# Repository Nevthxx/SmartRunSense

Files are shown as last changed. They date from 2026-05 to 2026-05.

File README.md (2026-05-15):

🏃‍♂️ SmartRunSense

IoT-Based Environmental Monitoring and Prediction System

C++ · Python · scikit-learn · Google Cloud · Firebase · ESP32

📖 Overview
Outdoor running offers major physical and mental health benefits, but environmental conditions such as heat, humidity, particulate matter, and gas pollutants can introduce serious physiological stress.
SmartRunSense is an IoT-based environmental intelligence system designed to help runners make safer and more informed training decisions. It combines real-time sensor data, cloud infrastructure, and machine learning forecasting to provide both live and predictive environmental insights.
The system integrates wearable and stationary IoT nodes, cloud-based data storage, ML-driven forecasting, and a mobile application for visualization and decision support.

🗺️ System Architecture
SmartRunSense is built across four logical layers:
Edge Layer (IoT Devices):
Wearable devices and stationary Smart Poles equipped with environmental sensors.
Cloud Ingestion & Storage:
Google Firestore acts as the central real-time database.
Cloud Processing Layer:
Google Cloud Run microservice running a scikit-learn-based forecasting engine.
Application Layer:
Mobile app for live monitoring, historical analysis, and predictive insights.

✨ Key Features

📡 Real-Time Environmental Monitoring
Continuous data collection from wearable and Smart Pole IoT nodes.

🤖 Machine Learning Forecasting
Predicts environmental conditions up to 7 days ahead using a Random Forest Regressor.

📱 Mobile Application Dashboard
Provides live sensor data, analytics, and personalized run recommendations.

📅 Smart Scheduling System
Suggests optimal time slots for outdoor activity based on predicted environmental risk.

🛠️ Hardware Architecture
⌚ Wearable Device
Portable ESP32-based node (ESP32 DevKitC / ESP32-C3) designed for runners in motion.
🗼 Smart Pole (Stationary Node)
Fixed monitoring stations powered by ESP32-S3 for continuous environmental tracking in public areas.

🌡️ Sensor Suite
Both nodes integrate a shared set of sensors:
🌬️ ENS160 – Air quality (AQI, eCO₂, TVOC)
💧 AHT21 – Temperature & humidity
🏭 MQ135 – Gas pollution estimation (NOx, NH₃, smoke, benzene, etc.)
💨 SHARP GP2Y1010 – Dust/particulate matter detection
🧠 Machine Learning & Cloud Pipeline
⚙️ Execution: Cloud Run microservice triggered every 30 minutes via Cloud Scheduler
📊 Model: Random Forest Regressor (scikit-learn)
📈 Training Data: Last 14 days of sensor data (~20,000 records)
🔮 Forecast Horizon: 7 days ahead in 30-minute intervals (336 steps)
🎯 Outputs: Temperature, humidity, dust density, AQI, TVOC, CO₂, gas pollution %

🗄️ Database
🔥 Google Firestore
Stores real-time sensor readings and ML-generated forecasts with timestamped environmental metrics.

📱 Mobile Application
📊 Live Monitor: Real-time environmental conditions with a “Run Score” risk indicator
📅 Smart Schedule: Highlights safe vs risky time slots for outdoor running
📉 Analytics: Historical trends for air quality and pollutants
🌤️ Forecast: 7-day environmental predictions from the ML engine

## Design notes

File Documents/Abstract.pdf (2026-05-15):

## SmartRunSense: An IoT Based Environmental Monitoring and Prediction System for Safer Outdoor Running

## Abstract

Outdoor running is one of the most accessible and widely practiced forms of physical exercise, providing cardiovascular and mental health benefits. However, the thermodynamic and respiratory stresses experienced during outdoor training are strongly influenced by environmental conditions. Ambient temperature and humidity determine the rate of heat exchange between the body and the surroundings, while airborne particulate matter and gaseous pollutants alter respiratory efficiency and gas exchange (Brook et al., 2010; WHO, 2018). Understanding these interactions is critical for optimizing performance and reducing physiological risk during sustained exercise. Despite these risks, runners often rely on general weather forecasts that do not accurately represent localized environmental conditions at specific training tracks or open-air exercise spaces, which may expose them to heat stress, dehydration, or respiratory irritation without their knowledge (Li et al., 2019).

To address this challenge, SmartRunSense proposes an Internet of Things (IoT) based environmental monitoring and prediction system that enables runners to make informed decisions about when and where to train. The system combines real time environmental sensing, cloud based data storage, predictive analytics using machine learning, and a mobile application to provide both current and forecasted environmental conditions. By continuously monitoring atmospheric variables and analyzing their temporal patterns, the system identifies safer time periods for outdoor running and supports optimized training schedules.

The environmental monitoring component consists of stationary sensing units, referred to as Smart Poles, which collect high resolution data from multiple environmental sensors. Each Smart Pole is built around an ESP32 microcontroller, chosen for its Wi-Fi communication capabilities and low power consumption. Temperature and relative humidity are measured using an AHT21 digital sensor, enabling assessment of thermoregulatory stress via sweat evaporation efficiency. Air quality is evaluated using an ENS160 sensor, which provides measurements for Air Quality Index (AQI), equivalent carbon dioxide (eCO₂), and Total Volatile Organic Compounds (TVOC). Additional gas pollutants are estimated using a MQ135 sensor, while particulate concentration is measured using an optical dust sensor (GP2Y1010AU0F / DSM501A), which detects infrared light scattering caused by suspended particles. This multi-sensor setup captures a comprehensive environmental profile relevant to both thermodynamics and respiratory exposure (Kumar et al., 2015).

Data collected by the Smart Poles are transmitted via Wi-Fi to a cloud database (Google Firebase Firestore), where they are timestamped and stored. These continuous datasets enable the system to perform predictive analysis using a Random Forest regression model, trained on historical environmental data to forecast temperature, humidity, dust concentration, AQI, and pollutant levels at 30-minute intervals for up to seven days. By analyzing temporal features such as hour of the day and day of the week, the model identifies patterns and predicts periods when environmental conditions are safer for outdoor activity.

In parallel, SmartRunSense incorporates a wearable device that provides runners with real-time, localized environmental information in their breathing zone. The wearable is built on an ESP32-S3 microcontroller with integrated Wi-Fi and Bluetooth Low Energy (BLE), combined with an ENS160 air-quality sensor and AHT21 temperature and humidity sensor. The device measures eCO₂, TVOC, temperature, and humidity near the runner and displays these values on a compact OLED screen. A simple touch-based interface allows users to check current environmental conditions at a glance. Unlike the Smart Poles, the wearable does not transmit data to the cloud; it functions as an awareness tool, providing immediate feedback on the air the runner is breathing.

The SmartRunSense mobile application consolidates data from the Smart Poles and predictive model, allowing users to visualize both current environmental measurements and forecasted conditions. Parameters such as temperature, humidity, AQI, dust levels, and pollutant concentrations are presented in a user-friendly format. The app highlights recommended running periods based on predicted environmental safety, enabling runners to plan training sessions while minimizing exposure to heat stress or air pollutants.

By integrating environmental physics principles, IoT sensing, and predictive analytics, SmartRunSense offers a comprehensive system that supports safer outdoor exercise. It enables runners to make data driven decisions based on both the current conditions in their immediate environment and predictions of how these conditions may change over time. This combination of stationary monitoring, wearable awareness, machine learning based forecasting, and mobile visualization demonstrates the potential of technology driven environmental assessment to improve athletic safety and performance in outdoor activities.

## References

1. Brook, R. D., Rajagopalan, S., Pope III, C. A., Brook, J. R., Bhatnagar, A., Diez-Roux, A. V., ... & Kaufman, J. D. (2010). Particulate matter air pollution and cardiovascular disease: An update to the scientific statement from the American Heart
Association. Circulation, 121(21), 2331–2378.
2. World Health Organization (WHO). (2018). Air pollution and child health: Prescribing clean air. Geneva: WHO.
3. Li, X., et al. (2019). Wearable environmental sensing for personalized exposure assessment. Sensors, 19(11), 2573.
4. Kumar, P., et al. (2015). The rise of low-cost sensing for managing air pollution in cities. Environment International, 75, 199–205.

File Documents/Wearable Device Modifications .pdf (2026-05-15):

# SmartRunSense

## Wearable Device

ESP32 DevKitC vs ESP32-C3 Super Mini

## Shared Components: Sensors, Display & Battery

The following components are identical in both wearable builds. Specifications and usage are the same regardless of which microcontroller board is selected.

Component | Specification | DevKitC build | C3 Super Mini build

Sensors

ENS160 Air quality sensor | eCO₂: 400–65,000 ppm TVOC: 0–65,000 ppb AQI index · I²C · LGA-9 · 3×3×0.9 mm | ✓ Same | ✓ Same
AHT21 Temp + humidity | ±0.3°C, range −40 to +85°C ±2% RH · I²C · SMD · 3×3×0.8 mm | ✓ Same | ✓ Same
SSD1306 OLED 0.49" display | 64×32 px · I²C · ~14×11 mm glass Timeout off after 5 s, wake on touch | ✓ Same | ✓ Same

Power & Charging

LiPo battery 3.7 V rechargeable | 200 mAh · 3.7 V · JST SH 1.0 mm ~30×15×4 mm cell | 200 mAh | 200 mAh
MCP73831T LiPo charger IC | 100 mA single-cell · SOT-23-5 2.9×1.6 mm · USB-C input | ✓ Same | ✓ Same
USB-C connector Charge + flash | GCT USB4085 mid-mount 8.9×3.5 mm SMD | ✓ Same | ✓ Same

Touch Interface

Capacitive touch
User input button

Native ESP32 GPIO touch channel Exposed copper pad on PCB
surface

✓ Built-in GPIO ✓ Built-in GPIO

## Microcontroller Board Comparison

Direct comparison of the ESP32 DevKitC development board against the ESP32-C3 Super Mini for use in the SmartRunSense wearable. Green cells indicate the better choice for a wearable application; amber cells indicate where the DevKitC has an advantage.

Feature | ESP32 DevKitC | ESP32-C3 Super Mini

Hardware Specs

Board size | 55.3 × 28.0 mm | 22.5 × 18.0 mm
Board area | 1,548 mm² | 405 mm²
Processor | Xtensa LX6 dual-core | RISC-V single-core
Clock speed | 240 MHz | 160 MHz
Flash memory | 4 MB | 4 MB
SRAM | 520 KB | 400 KB
Usable GPIOs | 38 pins | 11 pins

Wireless

Wi-Fi | 802.11 b/g/n (Wi-Fi 4) | 802.11 b/g/n (Wi-Fi 4)
Bluetooth | BLE 4.2 | BLE 5.0
RF certification | FCC / CE (board) | FCC / CE (module)
Antenna | PCB trace on WROOM module | Built-in PCB trace

Power

Active current | ~80–120 mA | ~20–30 mA
Light sleep | ~10–15 mA | ~5 µA (deep sleep)
Est. battery life | ~3–5 h / 200 mAh | ~10–14 h / 200 mAh
Native USB OTG | No — needs CH340 bridge | Yes

Assembly & Soldering

Soldering method | Pin headers — plug in | SMD castellated pads
Support circuits needed | None — all on board | LDO + buttons + caps
Prototype difficulty | Very easy | Moderate
Production suitability | Poor — redundant parts | Good — compact custom PCB

GPIO Sufficiency for SmartRunSense

I²C (SDA + SCL) | ✓ 2 pins used | ✓ 2 pins used

Feature | ESP32 DevKitC | ESP32-C3 Super Mini
OLED RST + DC | ✓ 2 pins used | ✓ 2 pins used
Capacitive touch | ✓ 1 pin used | ✓ 1 pin used
Total GPIOs needed | 5 of 38 used | 5 of 11 used
Room for expansion | 33 GPIOs spare | 6 GPIOs spare

## Enclosure Box Size Comparison

Estimated enclosure dimensions for the assembled wearable device including board, sensors, OLED display, battery, and wiring clearance. Based on DevKitC box dimensions of 88 × 68 × 55 mm as the baseline.

Dimension | DevKitC wearable box | C3 Super Mini box | Saving

Enclosure Outer Dimensions

Length (longest side) | 88 mm | 55 mm | −33 mm (−37%)
Width | 68 mm | 58 mm | −10 mm (−15%)
Depth / height | 55 mm | 45 mm | −10 mm (−18%)

Volume & Area

Footprint area (L × W) | 5,984 mm² | 3,190 mm² | −2,794 mm² (−47%)
Total volume (L × W × D) | ~328,000 mm³ | ~143,550 mm³ | −184,450 mm³ (−56%)

What Drives the Size Reduction

Board length contribution | 55.3 mm board | 22.5 mm board | −32.8 mm saved
OLED glass (unchanged) | ~14 mm wide | ~14 mm wide | No change
Battery (unchanged) | ~30 × 15 mm | ~30 × 15 mm | No change
Wiring clearance | ~15 mm each side | ~10 mm each side | −5 mm / side
Depth (thinner layout) | 55 mm | ~45 mm | Flatter battery fit possible

Wrist Wearability

Fits standard watch case? | No — 88 mm too long | Marginal — 55 mm is borderline | Closer to wearable size
Recommended enclosure type | Belt clip / armband | Wrist band / armband | Better form factor

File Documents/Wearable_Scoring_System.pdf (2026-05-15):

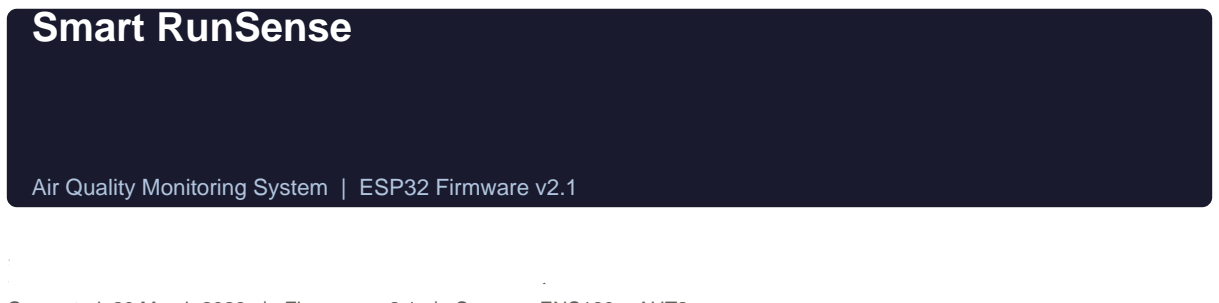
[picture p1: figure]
Smart RunSense

Air Quality Monitoring System | ESP32 Firmware v2.1
Scoring System Technical Report Mechanical Analysis of Air Quality Interpretation and Runner Score Computation
Generated: 20 March 2026 | Firmware: v2.1 | Sensors: ENS160 + AHT2x

### 1. System Overview

Smart RunSense is an embedded air quality monitoring system designed specifically for outdoor runners. Unlike standard Air Quality Index (AQI) systems that are calibrated for general population exposure over long periods, Smart RunSense computes a Runner Score — a real-time composite metric that accounts for both pollutant hazard and physical comfort conditions encountered during exercise. The score drives a five-band status classification displayed on the OLED screen and transmitted to Firebase Firestore.

Sensor | Parameter | Output Unit | Role in Score
ENS160 | eCO2 | ppm | Health AQI — primary
ENS160 | TVOC | ppb | Health AQI — primary
AHT2x | Temperature | °C | Comfort penalty
AHT2x | Humidity | % RH | Comfort penalty

Table 1 — Sensor inputs and their roles in the scoring pipeline.

### 2. Scoring Pipeline Architecture

The Runner Score is produced by a two-layer computation pipeline. Layer 1 evaluates atmospheric health through pollutant concentrations. Layer 2 applies a comfort-based scaling factor derived from temperature and humidity. The final score is bounded to [0, 100] and is intentionally asymmetric: poor air quality cannot be rescued by ideal comfort conditions, but extreme heat or humidity degrades performance even in chemically clean air.

Stage | Inputs | Output | Method
1a | eCO2 (ppm) | eCO2 Score | Piecewise linear
1b | TVOC (ppb) | TVOC Score | Piecewise linear
1c | Stage 1a + 1b | Health AQI | Dominant pollutant (min)
2a | Temperature (°C) | Temp Score | Piecewise linear
2b | Humidity (% RH) | Humidity Score | Piecewise linear
2c | Stage 2a + 2b | Comfort Score | Weighted blend 60/40
2d | Comfort Score | Comfort Multiplier | Linear scale [0.5 – 1.0]
3 | Health AQI x Multiplier | Runner Score | Multiplicative

Table 2 — Full computation pipeline with stage identifiers.

### 3. Individual Sensor Scoring Functions

### 3.1 eCO2 Score — getECO2Score(eco2)

Carbon dioxide equivalent (eCO2) is used as a proxy for overall indoor/outdoor air freshness and ventilation quality. The ENS160 derives eCO2 from metal oxide sensor readings, calibrated to the Adafruit AHT temperature and humidity sensor for temperature and RH compensation. Higher eCO2 concentrations indicate stale, poorly ventilated air which reduces oxygen availability for an exercising runner.

eCO2 Range (ppm) | Score | Condition
< 400 | 100.0 | Pristine — fresh outdoor air
400 – 5000 | Linear decrease from 100 to 0 | Moderate to severely polluted
> 5000 | 0.0 | Hazardous — do not run

Linear interpolation formula for 400 – 5000 ppm range:
eCO2 Score = max(0, 100 - ((eCO2 - 400) / 46.0))
Slope derivation: (100 - 0) / (5000 - 400) = 100 / 4600 = 0.02174 => 1/46.0 per ppm

### 3.2 TVOC Score — getTVOCScore(tvoc)

Total Volatile Organic Compounds (TVOC) represent a broad class of chemical pollutants including benzene, formaldehyde, and other volatile hydrocarbons. Elevated TVOC is associated with traffic emissions, industrial output, and off-gassing materials. During exercise, respiratory rate increases 10–20x, dramatically increasing pollutant intake, making TVOC a critical health factor for runners.

TVOC Range (ppb) | Score | WHO Classification
< 65 | 100.0 | Clean — no irritation
65 – 2200 | Linear decrease from 100 to 0 | Moderate to very high pollution
> 2200 | 0.0 | Extreme — hazardous exposure

Linear interpolation formula for 65 – 2200 ppb range:
TVOC Score = max(0, 100 - ((TVOC - 65) / 21.35))
Slope derivation: 100 / (2200 - 65) = 100 / 2135 = 0.04684 => 1/21.35 per ppb

### 4. Health AQI — Dominant Pollutant Model

The Health AQI does not average the two pollutant scores. Instead, it takes the strict minimum — the dominant pollutant model. This mirrors the methodology used by the US EPA's official AQI standard, where the overall air quality is determined by whichever single pollutant is worst.
Health AQI = min( eCO2 Score, TVOC Score )
Rationale: If eCO2 is excellent (Score = 95) but TVOC is dangerously high (Score = 12), averaging would produce a misleadingly acceptable result of 53.5. The dominant pollutant model correctly yields 12, accurately reflecting the hazardous chemical exposure the runner would experience.

### 5. Comfort Layer — Temperature and Humidity

### 5.1 Temperature Score — getTempScore(temp)

The optimal running temperature range is defined as 10 – 20°C based on exercise physiology research showing minimal cardiovascular strain and optimal thermoregulation in this window. Outside this range, the body expends additional energy on thermal regulation, reducing performance and increasing cardiac load.

Temperature Range | Score Formula | Physiological Rationale

10 – 20°C | 100.0 (flat) | Optimal running range
0 – 10°C | 50 + (T x 5.0) | Cold stress — muscle inefficiency
20 – 40°C | max(0, 100 - (T-20)x5) | Heat stress — hyperthermia risk
< 0°C or > 40°C | 0.0 | Extreme — dangerous to run

### 5.2 Humidity Score — getHumScore(hum)

Relative humidity directly affects the body's ability to cool itself through sweat evaporation. At humidity above 60%, sweat evaporation efficiency drops significantly, impairing thermoregulation. Below 40%, the air is too dry, increasing respiratory tract stress, dehydration risk, and airway irritation during heavy breathing.

Humidity Range | Score Formula | Effect
40 – 60% RH | 100.0 (flat) | Optimal evaporative cooling
10 – 40% RH | (H - 10) x 3.33 | Increasing dryness stress
60 – 90% RH | max(0, 100-(H-60)x3.33) | Decreasing sweat efficiency
< 10% or > 90% | 0.0 | Extreme — dangerous conditions

### 5.3 Comfort Score and Multiplier

Temperature and humidity scores are blended into a single Comfort Score using a weighted average that gives greater priority to temperature (60%) over humidity (40%), consistent with physiological evidence that ambient temperature is the stronger determinant of running performance degradation.
Comfort Score = (Temp Score x 0.6) + (Humidity Score x 0.4)
The Comfort Score is then converted to a multiplicative penalty factor — the Comfort Multiplier — which ranges from 0.5 (worst possible comfort) to 1.0 (perfect comfort). This multiplier is applied to the Health AQI.
Comfort Multiplier = 0.5 + (Comfort Score / 200.0)
At Comfort Score = 0: Multiplier = 0.5 (50% penalty — maximum degradation) At Comfort Score = 100: Multiplier = 1.0 (no penalty — perfect conditions)

### 6. Final Runner Score Computation

The Runner Score is the product of the Health AQI and the Comfort Multiplier:

### Runner Score = Health AQI x Comfort Multiplier

Expanding fully:
Runner Score = min(eCO2_Score, TVOC_Score) x [ 0.5 + (((Temp_Score x 0.6) + (Hum_Score x 0.4)) /
200) ]
Design Property | Behaviour | Why it Matters
Asymmetric penalty | Comfort cannot improve Health AQI above its raw value Prevents false reassurance in polluted environments
Dominant pollutant | Worst pollutant dictates Health AQI entirely | One toxic gas negates clean air elsewhere
Max comfort penalty | Even perfect air scores at most 50 in extreme heat/humidity Physiological limits respected regardless of air purity
Bounded output | Score always in [0, 100] | Consistent display and status classification

Table 3 — Key design properties of the Runner Score formula.

### 7. Status Classification Bands

The Runner Score is mapped to one of five status labels displayed on the OLED screen and stored in Firestore. The thresholds are calibrated to reflect real running safety guidelines rather than generic AQI categories:

DANGEROUS | UNSAFE | LIMIT | CAUTION | SAFE
0 | 30 | 50 | 70 | 85 | 100
Figure 1 — Runner Score status band distribution (0 – 100).
Score Range | Status | Recommended Action
85 – 100 | SAFE | Ideal conditions. Full training recommended.
70 – 84 | CAUTION | Acceptable. Monitor intensity, stay hydrated.
50 – 69 | LIMIT | Reduce intensity. Limit exposure time.
30 – 49 | UNSAFE | Avoid strenuous exercise. Short walks only.
0 – 29 | DANGEROUS | Do not run. Remain indoors if possible.

### 8. Worked Example — Typical Sri Lankan Afternoon Run

The following example demonstrates the full computation pipeline using realistic sensor values for a roadside urban run in Colombo at 3 PM:

Parameter | Sensor Reading | Sub-score
eCO2 | 780 ppm | Score = max(0, 100 - (780-400)/46.0) = 91.7
TVOC | 310 ppb | Score = max(0, 100 - (310-65)/21.35) = 88.5
Temperature | 32°C | Score = max(0, 100 - (32-20)x5) = 40.0
Humidity | 78% RH | Score = max(0, 100 - (78-60)x3.33) = 40.1

Step-by-step computation:
Health AQI = min(91.7, 88.5) = 88.5
Comfort Score = (40.0 x 0.6) + (40.1 x 0.4) = 24.0 + 16.04 = 40.04
Comfort Multiplier= 0.5 + (40.04 / 200.0) = 0.700
Runner Score = 88.5 x 0.700 = 61.95 → Status: LIMIT

Interpretation: Although the air pollutant levels are relatively acceptable (Health AQI = 88.5), the extreme heat and high humidity of a Colombo afternoon impose a 30% comfort penalty, pulling the final score into the LIMIT zone. The system correctly advises the runner to reduce intensity — a medically sound recommendation given the combined thermal and chemical stress.

### 9. Sensor Compensation

The ENS160 TVOC and eCO2 readings are temperature and humidity compensated in firmware before score calculation. The AHT2x readings are fed back into the ENS160 at each measurement cycle:

ens160.setTempCompensation(temp.temperature); ens160.setRHCompensation(hum.relative_humidity);
This ensures that elevated temperature does not artificially inflate eCO2 and TVOC readings, which is a common error in uncompensated metal oxide sensor deployments. All scores are therefore computed on environmentally corrected concentration values.

### 10. Data Output and Storage

Every 60 seconds, a complete measurement document is written to Google Firestore under the path sensor_data/esp32_0/readings/{YYYY-MM-DDTHH:MM}. The document includes all raw sensor values, all intermediate scores, the final Runner Score, and battery telemetry:

Firestore Field | Type | Description
temperature | double | AHT2x temperature (°C)
humidity | double | AHT2x relative humidity (%)
aqi | int | ENS160 native AQI index (1–5)
eco2 | int | Compensated eCO2 (ppm)
tvoc | int | Compensated TVOC (ppb)
runner_aqi | double | Computed Runner Score (0–100)
battery_voltage | double | Measured battery voltage (V)
battery_percent | int | Derived battery percentage (%)
timestamp | string | ISO 8601 timestamp (local time +05:30)
Smart RunSense | ESP32 Firmware v2.1 | Sensors: ENS160 + AHT2x | Scoring Engine: calculateRunnerAQI() | Report generated 20 March
2026

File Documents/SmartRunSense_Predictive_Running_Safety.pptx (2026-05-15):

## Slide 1

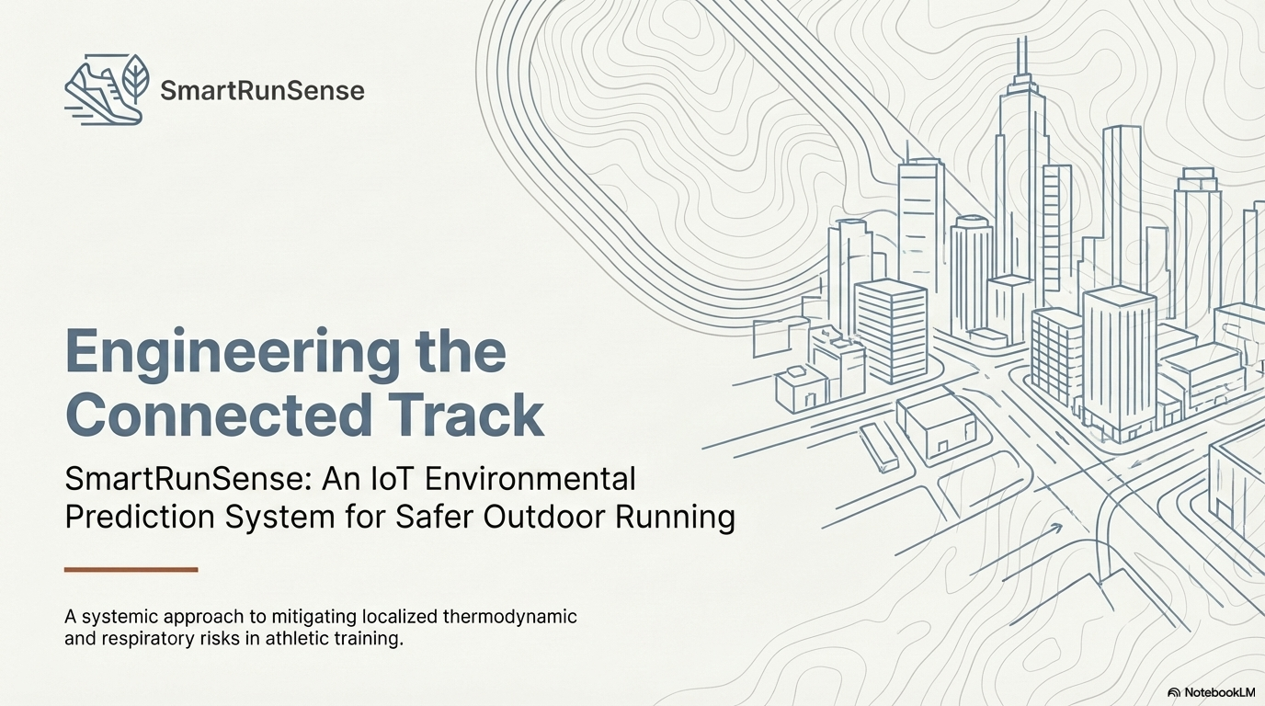
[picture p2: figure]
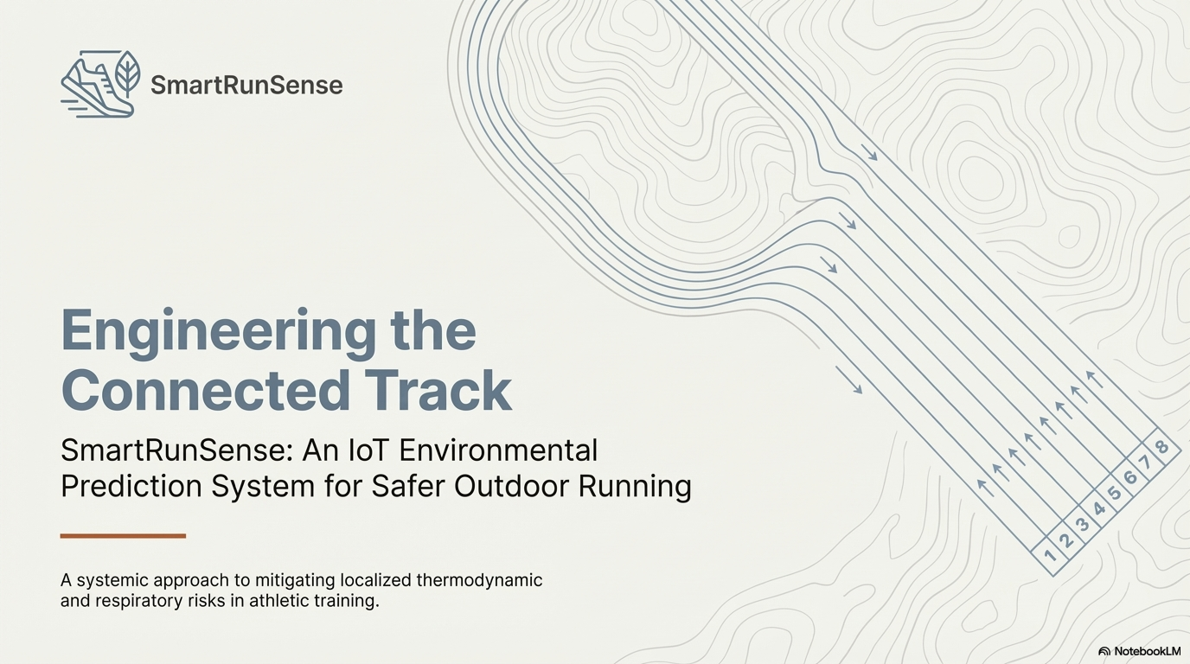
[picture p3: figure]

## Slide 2

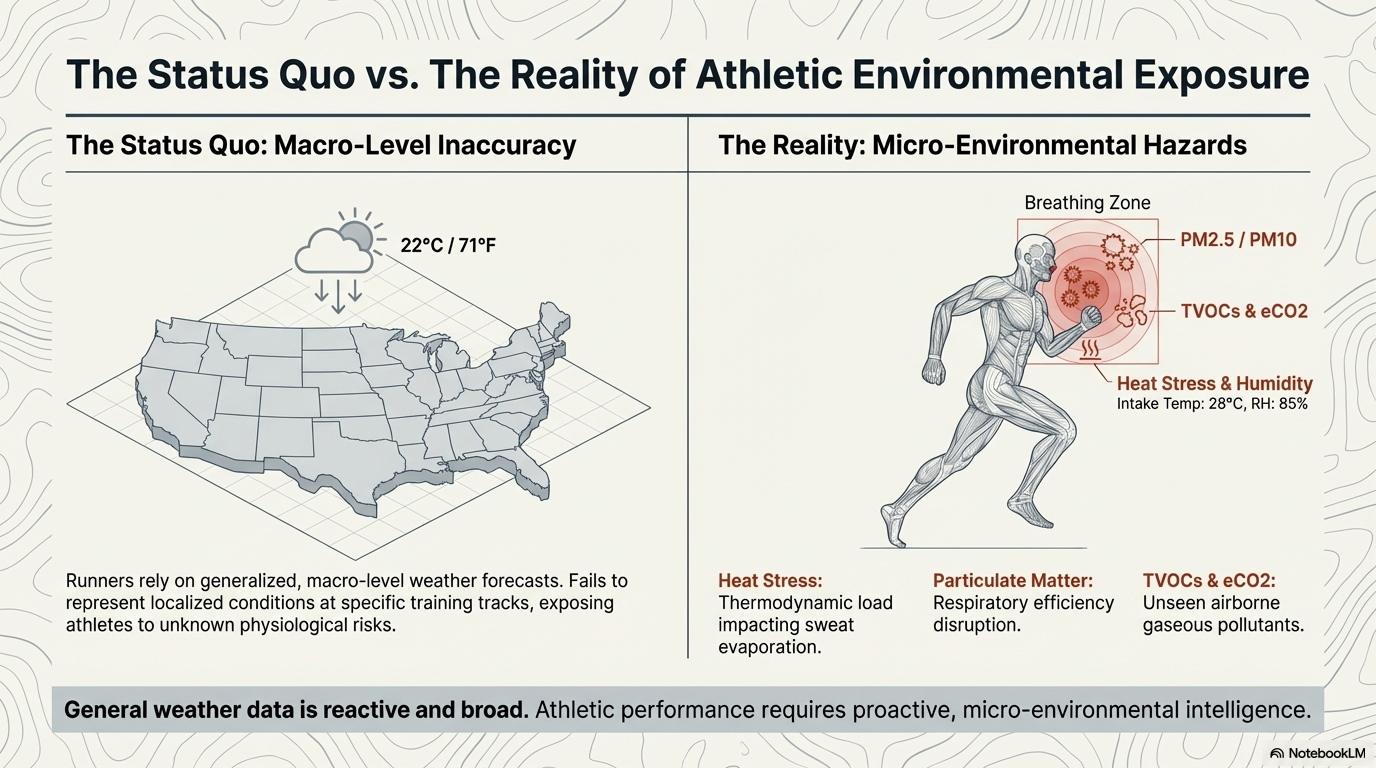
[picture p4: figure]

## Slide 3

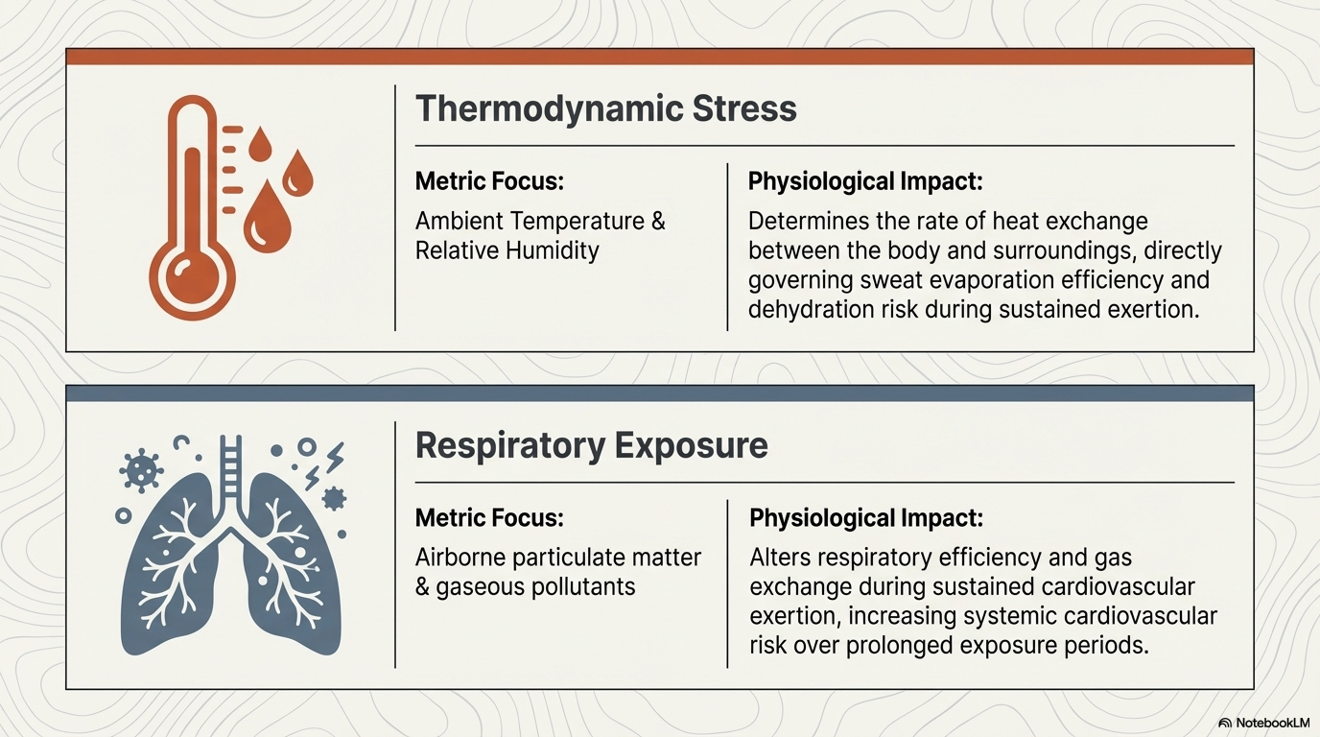
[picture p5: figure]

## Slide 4

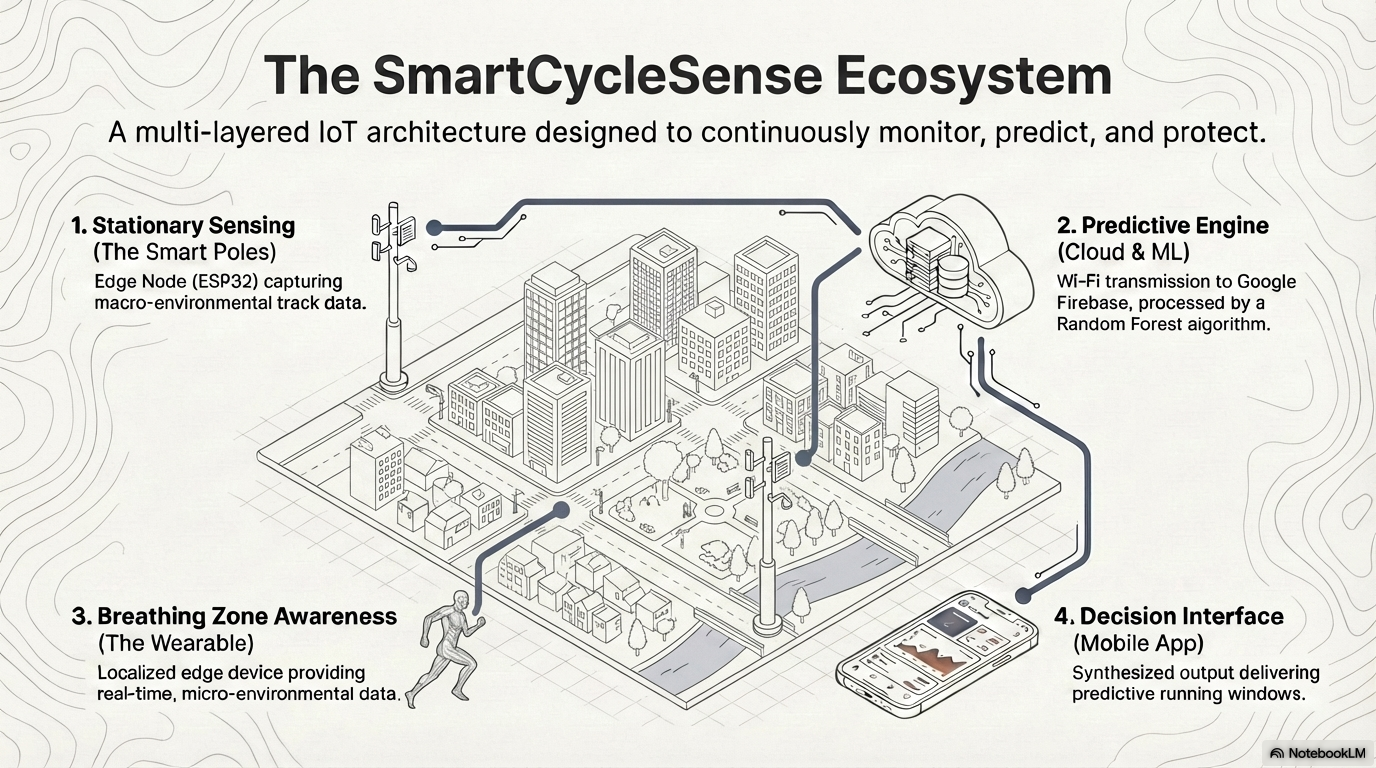
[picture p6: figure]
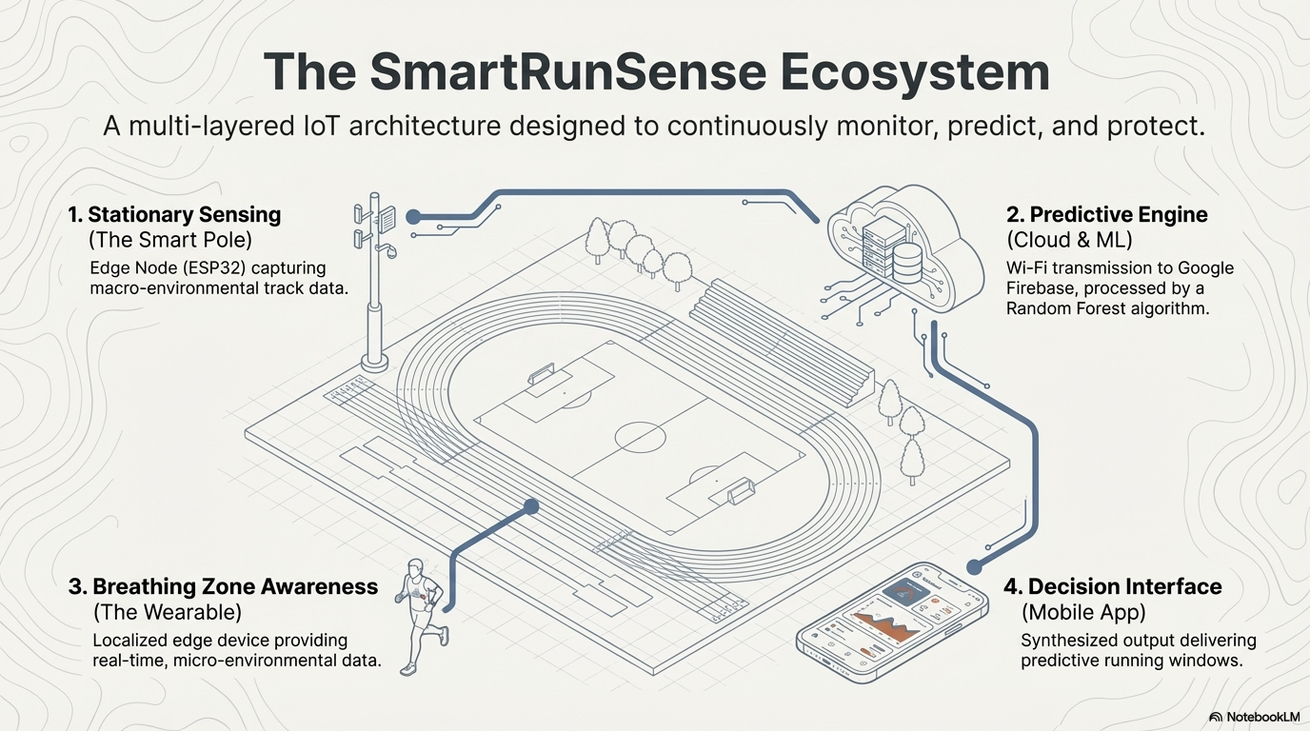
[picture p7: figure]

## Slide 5

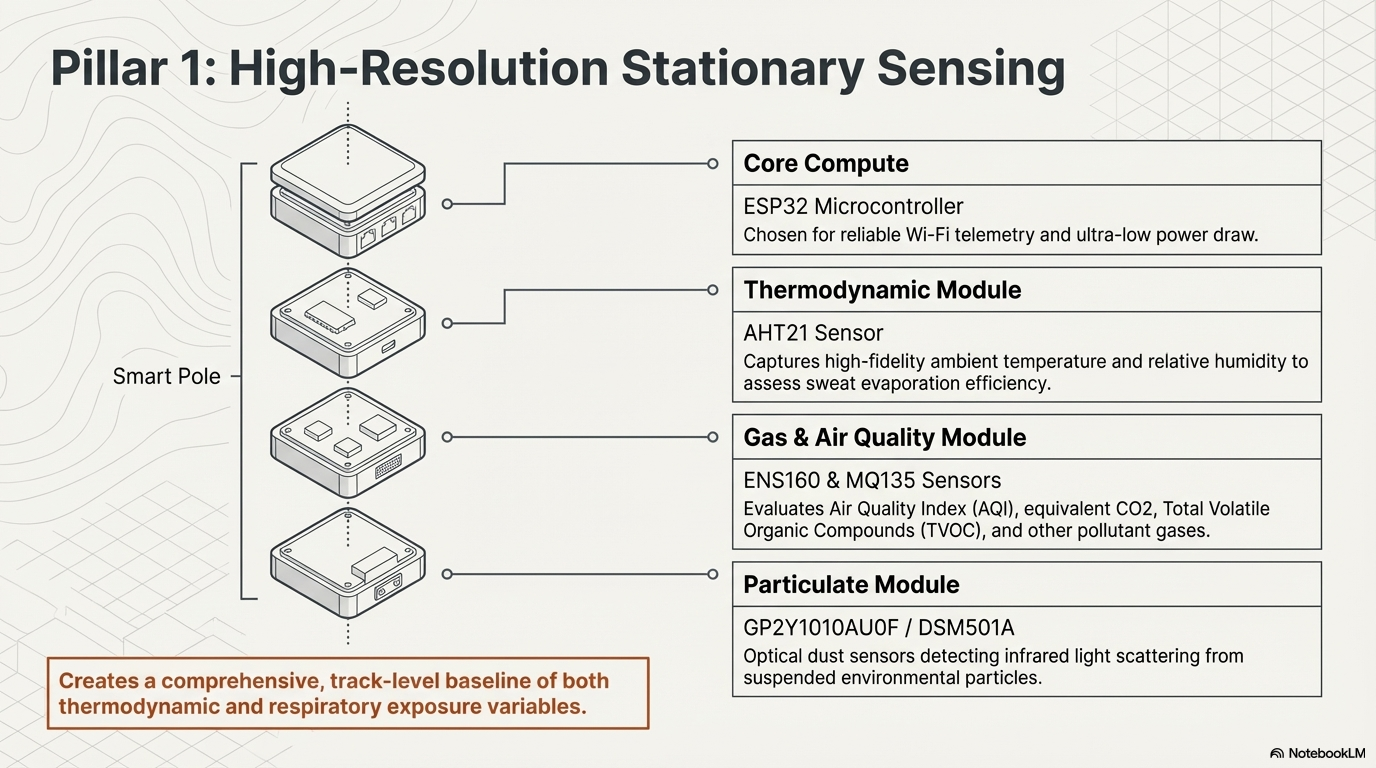
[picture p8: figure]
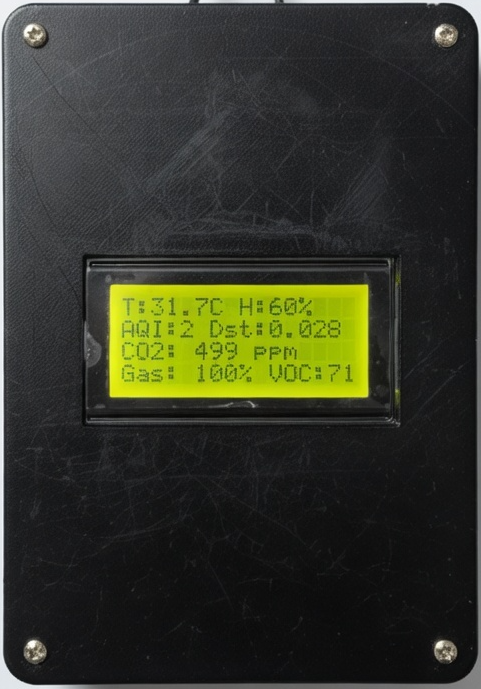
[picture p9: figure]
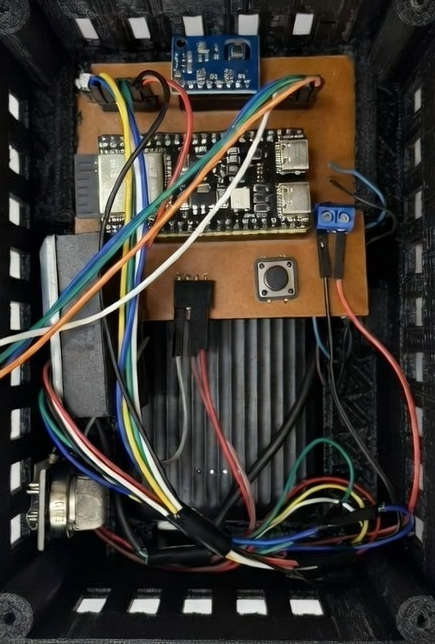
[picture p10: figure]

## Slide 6

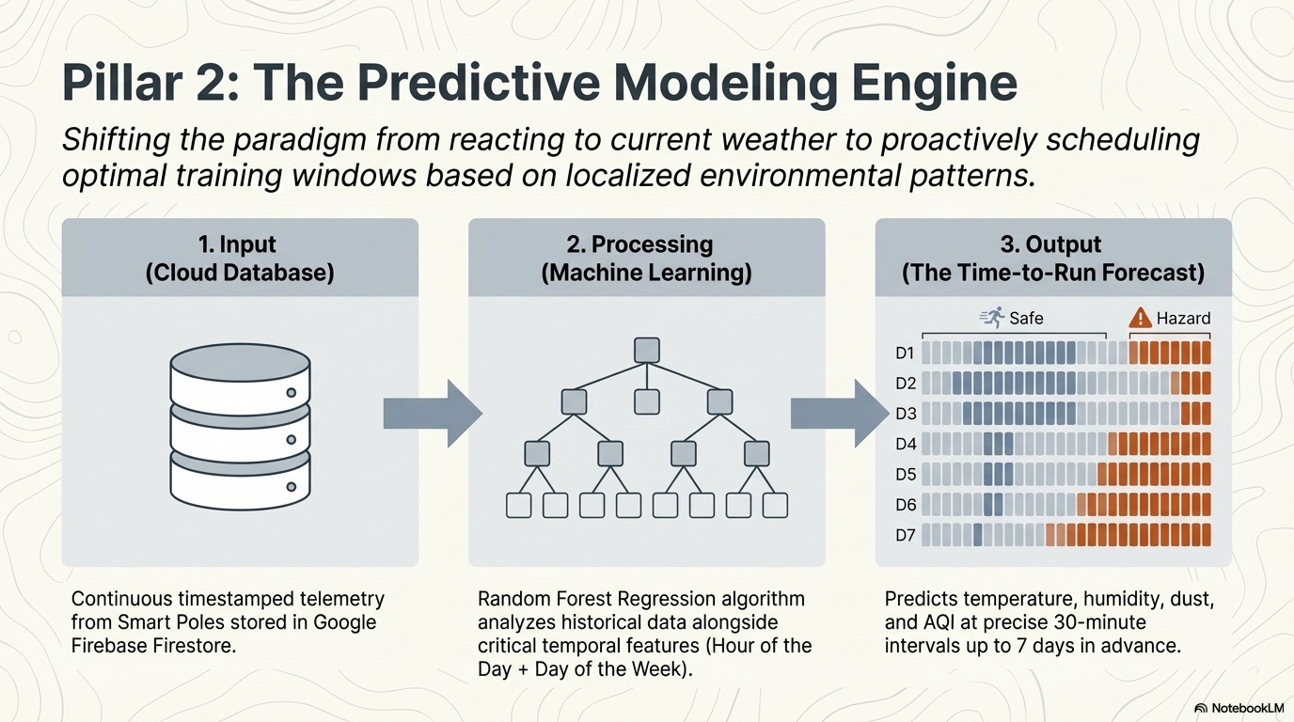
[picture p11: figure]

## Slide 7

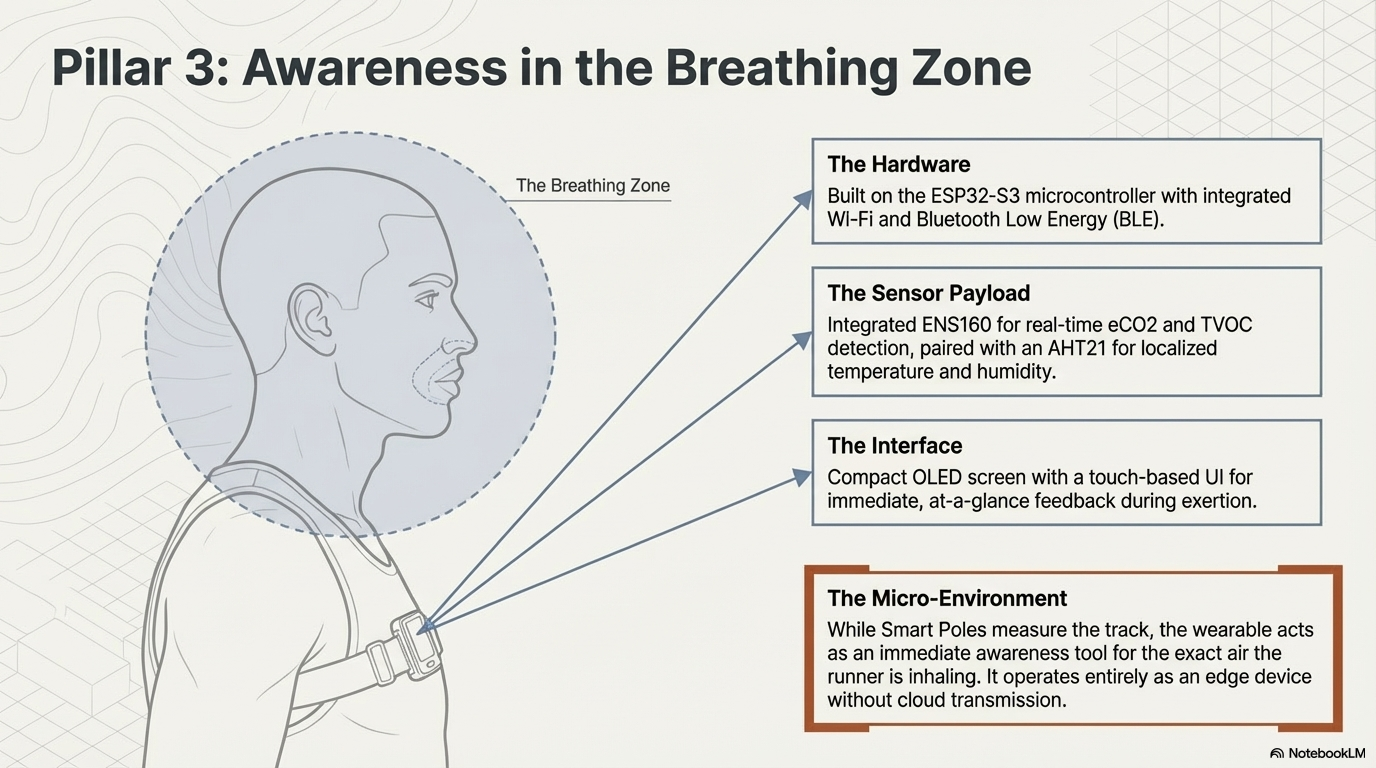
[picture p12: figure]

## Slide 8

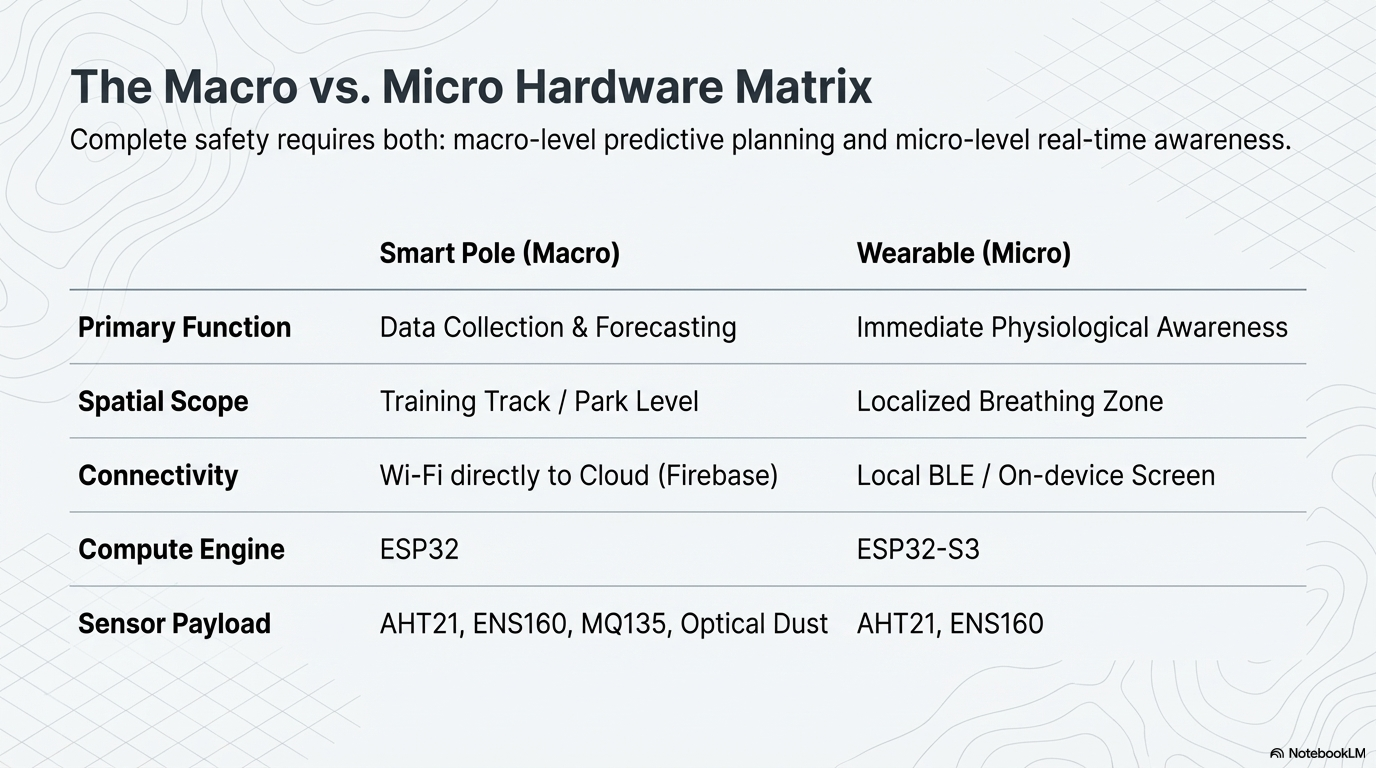
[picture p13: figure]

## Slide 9

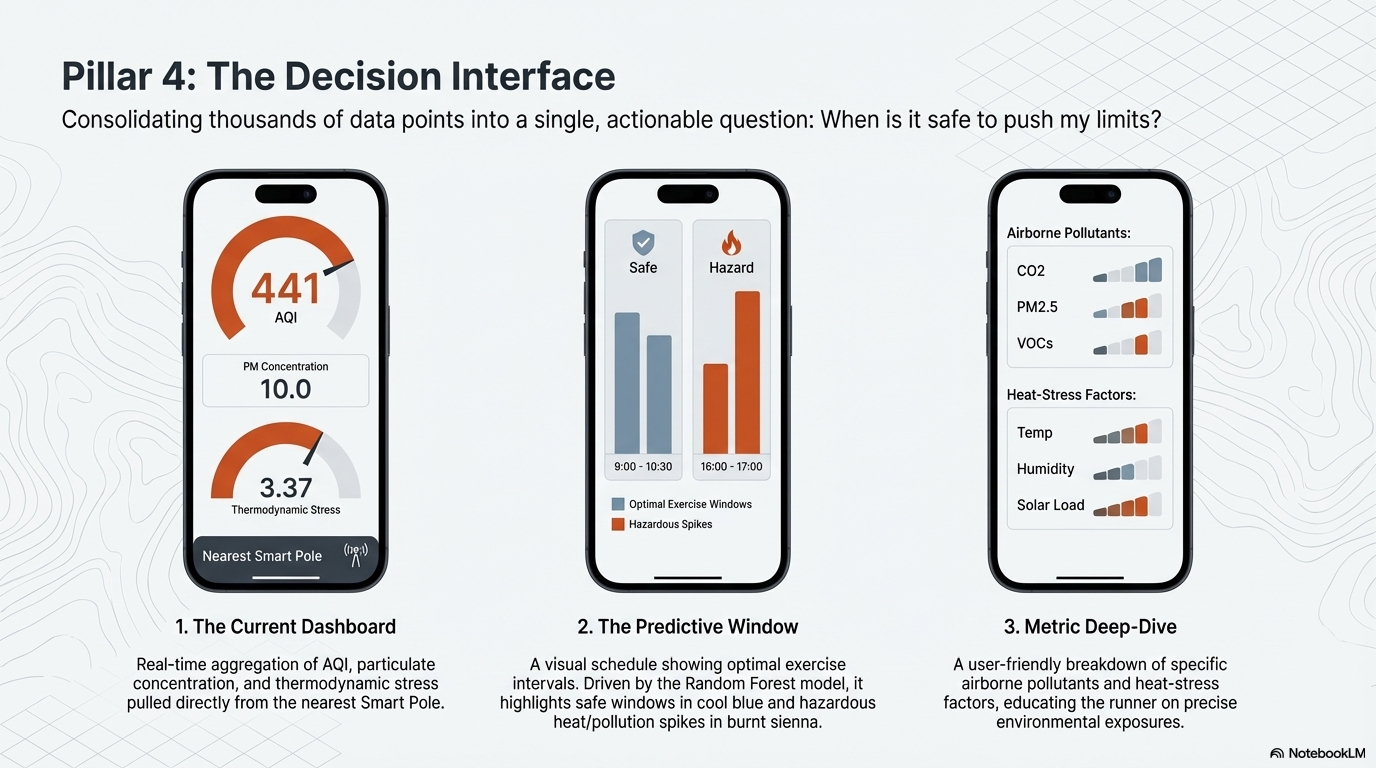
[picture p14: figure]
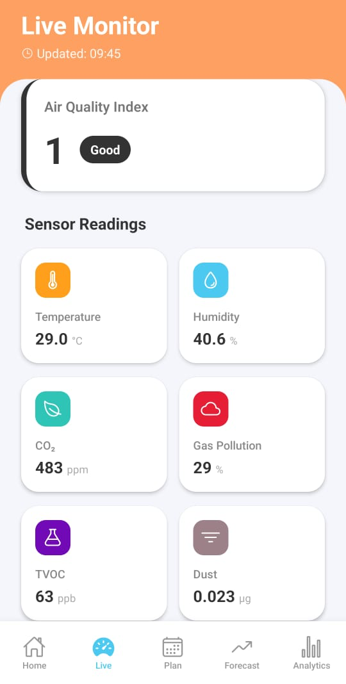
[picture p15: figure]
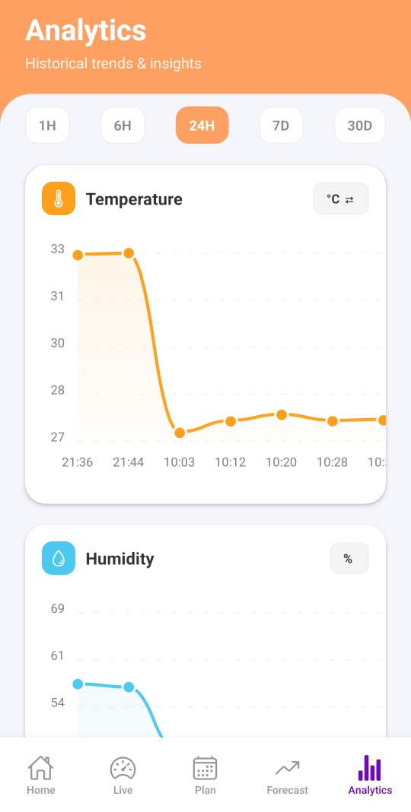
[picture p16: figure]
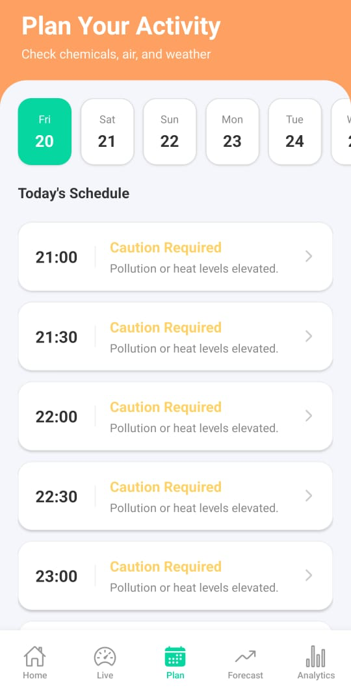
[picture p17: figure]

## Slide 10

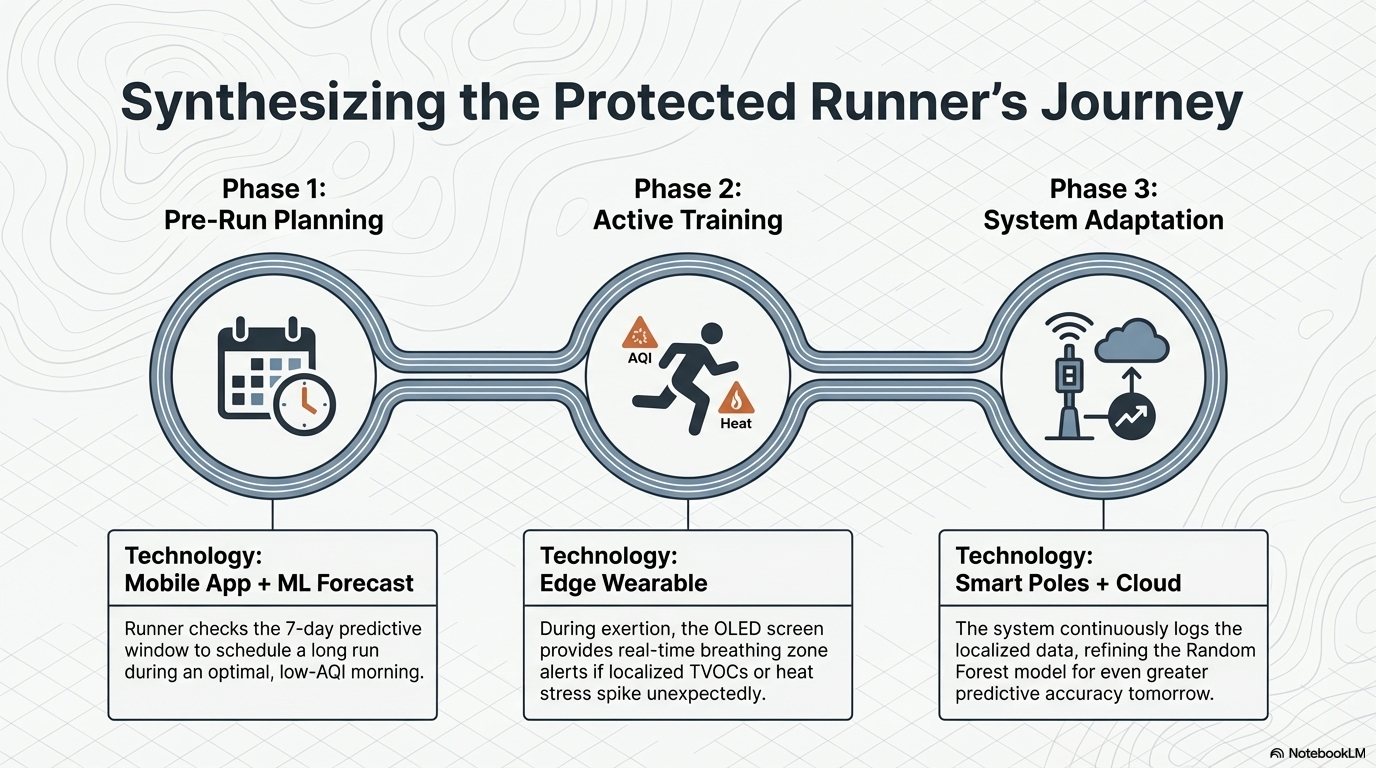
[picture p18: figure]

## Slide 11

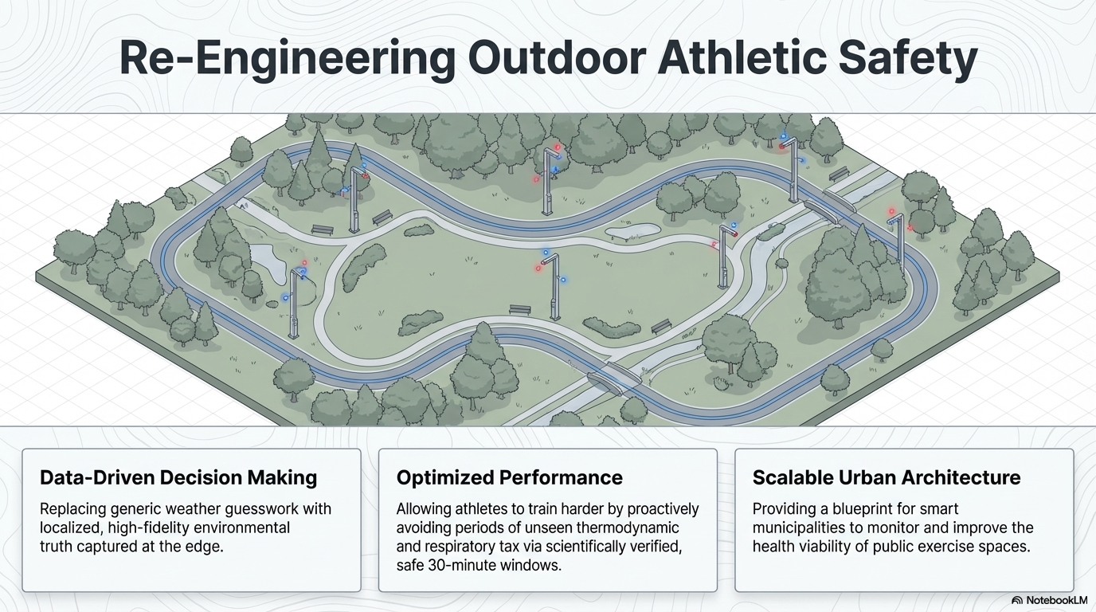
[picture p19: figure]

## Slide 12

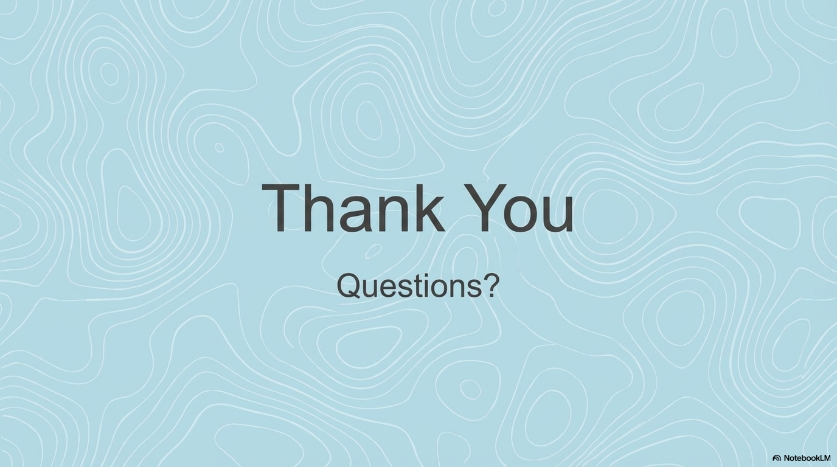
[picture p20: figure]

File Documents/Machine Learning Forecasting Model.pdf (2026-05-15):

## Machine Learning Forecasting Engine (Cloud Run Microservice)

### 1. System Overview

We built a Python program hosted on Google Cloud that automatically runs every 30 minutes. It reads the most recent environmental data, trains a new AI model on the spot, predicts future conditions, and uploads those results to our Firestore database.

### 2. Data Scope and Forecast Horizon

- Historical Data Used (The Input): The model queries the last 20,000 readings from Firestore, which roughly equates to the last 14 days of historical data. This 2-week window is specifically chosen to allow the model to learn daily patterns (e.g., temperatures rising at noon) as well as weekly cycles (e.g., weekends having different pollution levels than weekdays).
- Forecast Timeframe (The Output): The model predicts exactly 7 days into the future.
- Resolution: Predictions are generated in 30-minute intervals, resulting in 7 × 48 = 336 distinct prediction steps per execution.

### 3. The Variables (Features & Targets)

The model analyzes and predicts seven distinct environmental variables simultaneously:

1) Temperature
2) Humidity
3) Dust Density
4) AQI (Air Quality Index)
5) TVOC (Total Volatile Organic Compounds)
6) CO2 (eCO2-Equivalent Carbon Dioxide)
7) Gas Pollution Percentage (from the MQ135)

Each prediction is generated with the data and the time.

### 4. The Chosen Algorithm: Random Forest Regression

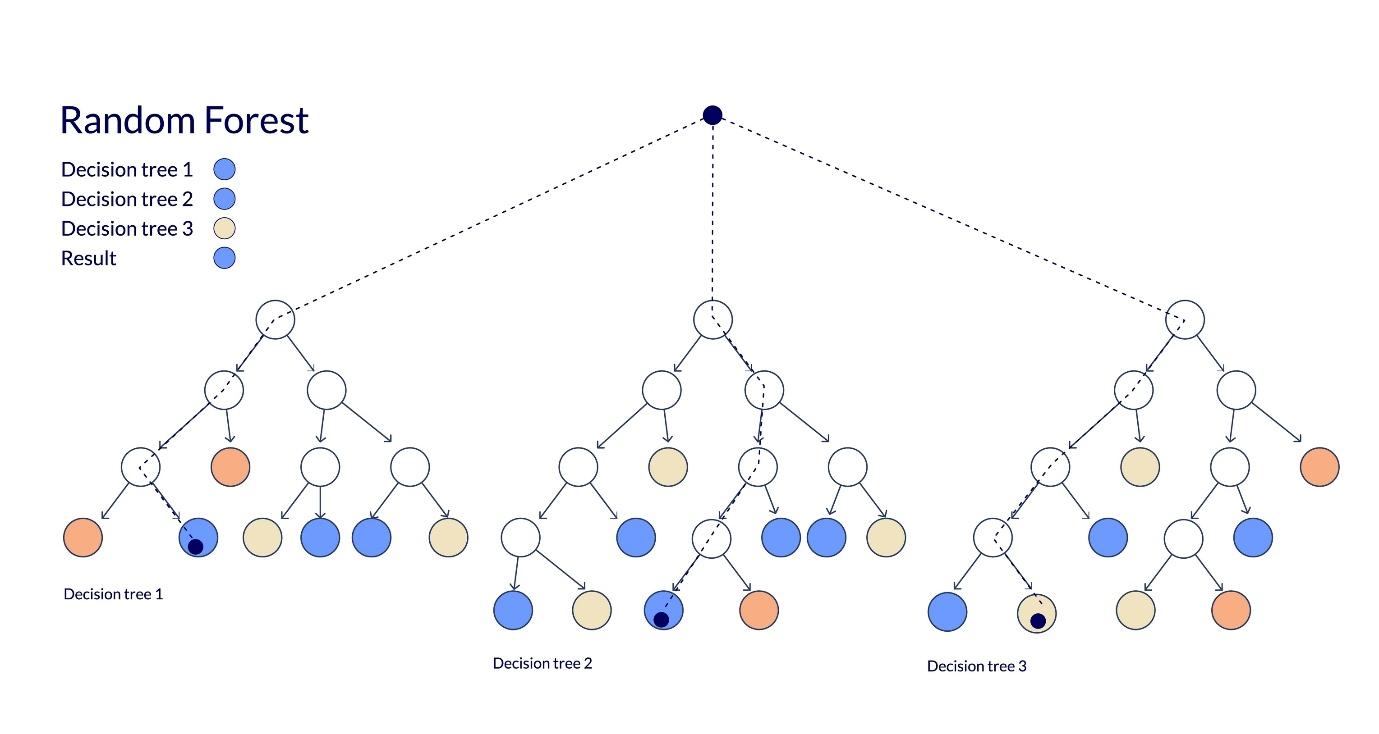
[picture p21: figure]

The code uses Random Forest Regressor from the scikit-learn library as the model. Random Forest is an ensemble learning method that builds dozens of "Decision Trees" during training and averages their predictions to output a highly accurate final result.

Why Random Forest was chosen over other algorithms:

- Handling Non-Linearity: Environmental data is highly non-linear. Linear Regression fails here, but Random Forest handles non-linear spikes exceptionally well.
- Compute Efficiency for Cloud Run: While Deep Learning models like LSTMs (Long Short-Term Memory networks) are great for time-series, they require heavy computing power, GPUs, and long training times. Random Forest trains in a matter of seconds using standard CPUs, making it perfect for a lightweight, cost-effective Cloud Run environment that triggers every 30 minutes.
- No Data Scaling Required: Neural networks require all data to be strictly normalized (scaled between 0 and 1). Random Forests do not care about the scale of the data, meaning we can feed raw Temperature (e.g., 30°C) and raw eCO2 (e.g., 400ppm) into the exact same model without complex pre-processing.

### 5. The Crucial Mechanism: How the Model Predicts the Future

The most critical part of this architecture is how it handles the time-series forecasting. It uses a technique called Autoregressive Recursive Forecasting.

Here is the exact step-by-step mechanism the code follows to predict the future:

Step 1: Resampling the Data;

- Sensor data can be messy and irregular. To fix this, our system automatically put the raw data into neat 30-minute intervals for the 14 days, giving the AI a clean and consistent timeline to learn from.
Step 2: Training 7 Parallel Models;

The code does not train just one model. It initializes a loop and trains seven separate Random Forest models. One dedicated entirely to Temperature, one to AQI, one to Dust, etc. Each model learns how its specific variable behaves based on the previous 30-minute window of all combined variables.

The Training Phase (Using all 14 Days): The model uses the full 14 days of data, but only to study and learn the rules.

- When the time is 12:00 PM, the temperature usually goes up.
- When AQI is high at 2:00 PM, it usually stays high at 2:30 PM.
- Weekends have less CO2 than weekdays.

Once the AI finishes reading those 14 days, it builds its Random Forest "brain" and completely throws the historical data away.

Step 3: The Recursive Prediction Loop (The "Sliding Window")

To predict 7 days into the future, the code relies on a feedback loop:

1) The Starting Point: It takes the very last known real sensor reading (e.g., today at 12:00 PM).
2) Step 1 Prediction: It feeds that real data into the ML models to predict what the air will look like at 12:30 PM.
3) The Feedback Loop: To predict 1:00 PM, the model no longer has real data. Therefore, it takes its own 12:30 PM prediction and feeds it back into itself as the new input to generate the 1:00 PM prediction.
4) Iteration: This cycle repeats 336 times. The outputs of step N become the inputs for step N+1, chaining together to generate a full 7-day forecast.

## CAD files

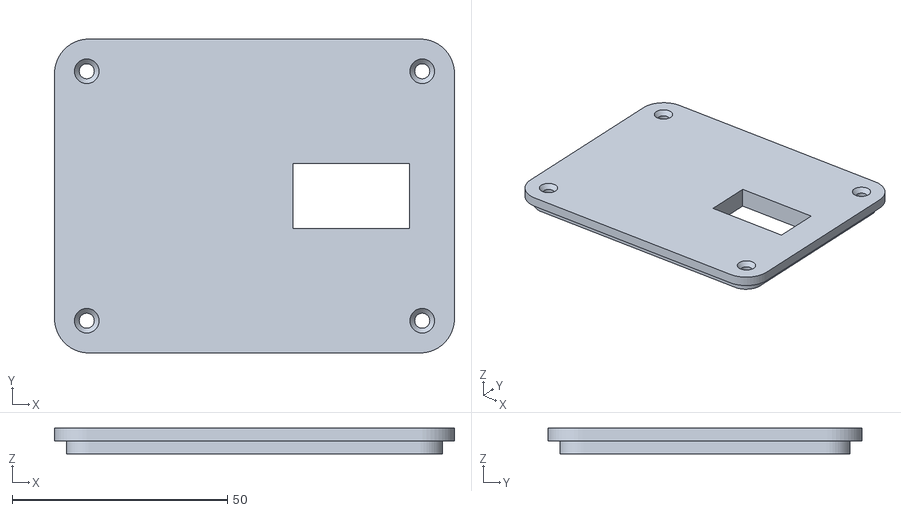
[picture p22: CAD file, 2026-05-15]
3D Design/Wearable_Lid.stl
93.0 x 73.0 x 6.00

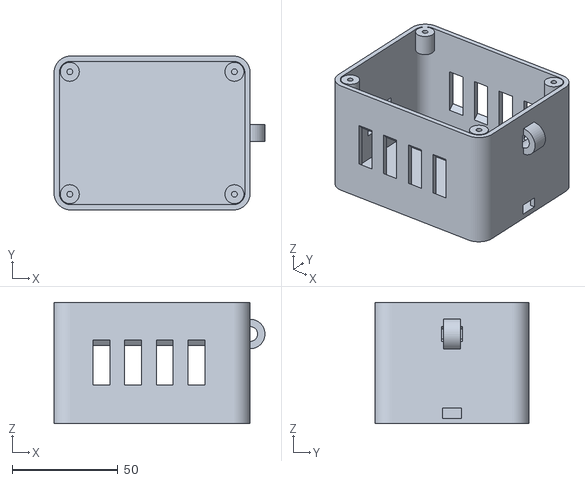
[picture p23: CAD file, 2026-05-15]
3D Design/Wearable_Box.stl
100.0 x 73.0 x 57.5

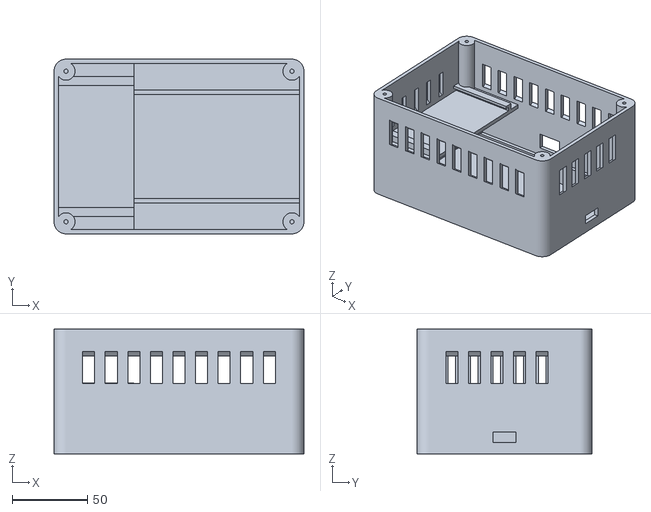
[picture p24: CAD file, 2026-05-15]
3D Design/Pole_Box.stl
166.0 x 116.0 x 83.0

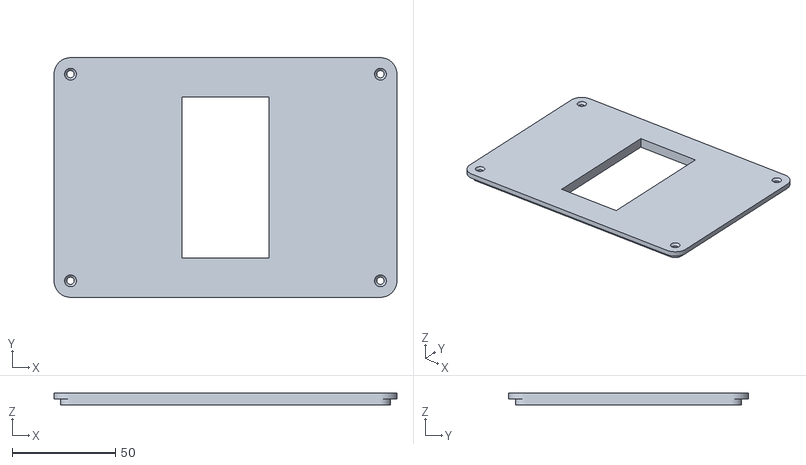
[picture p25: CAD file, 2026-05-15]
3D Design/Pole_Lid.stl
166.0 x 116.0 x 6.00

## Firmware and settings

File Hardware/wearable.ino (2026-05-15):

#include <WiFi.h>
#include <HTTPClient.h>
#include <ArduinoJson.h>
#include <WiFiClientSecure.h>
#include <time.h>
#include <Wire.h>
#include <SparkFun_ENS160.h>
#include <Adafruit_AHTX0.h>
#include <Adafruit_GFX.h>
#include <Adafruit_SSD1306.h>

/* ---------- OLED Display ---------- */
#define SCREEN_WIDTH 128
#define SCREEN_HEIGHT 64
#define OLED_RESET    -1 
#define SCREEN_ADDRESS 0x3C 

Adafruit_SSD1306 display(SCREEN_WIDTH, SCREEN_HEIGHT, &Wire, OLED_RESET);

/* ---------- WiFi ---------- */
#define WIFI_SSID "YOUR_WIFI_NAME"
#define WIFI_PASS "YOUR_WIFI_PASSWORD"

/* ---------- Firebase ---------- */
#define API_KEY    "YOUR_API_KEY"
#define PROJECT_ID "YOUR_PROJECT_ID"

/* ---------- Battery Monitoring ---------- */
#define BATTERY_PIN 6  // GPIO6 (ADC1_CH7) for battery voltage divider
#define ADC_RESOLUTION 4095.0  // 12-bit ADC
#define ADC_REF_VOLTAGE 3.3    // Reference voltage in volts
#define VOLTAGE_DIVIDER_RATIO 6.639  // Two equal resistors = ratio of 2

// Battery voltage thresholds (adjust based on your battery type)
// For LiPo: 4.2V = 100%, 3.7V = ~50%, 3.0V = 0%
#define BATTERY_MAX_VOLTAGE 4.2
#define BATTERY_MIN_VOLTAGE 3.2

/* ---------- Touch Sensor for Deep Sleep ---------- */
#define TOUCH_PIN 13  // GPIO 13 for TTP223 touch sensor

/* ---------- Sensors ---------- */
SparkFun_ENS160 ens160;
Adafruit_AHTX0 aht;

/* ---------- Timing ---------- */
unsigned long lastRead = 0;
const unsigned long READ_INTERVAL = 60000;

/* ---------- Touch Control ---------- */
unsigned long lastTouchTime = 0;
const unsigned long TOUCH_DEBOUNCE = 500;  // 500ms debounce
int lastTouchState = LOW;

/* ---------- RTC Memory (survives deep sleep) ---------- */
RTC_DATA_ATTR int bootCount = 0;  // Counts how many times we've woken up

String idToken = "";

/* ---------- Battery Functions ---------- */

// Read battery voltage from ADC
float readBatteryVoltage() {
  // Take multiple readings for accuracy
  int adcSum = 0;
  const int numReadings = 10;
  
  for (int i = 0; i < numReadings; i++) {
    adcSum += analogRead(BATTERY_PIN);
    delay(10);
  }
  
  int adcValue = adcSum / numReadings;
  
  // Convert ADC value to voltage at the divider (half of battery voltage)
  float dividerVoltage = (adcValue / ADC_RESOLUTION) * ADC_REF_VOLTAGE;
  
  // Calculate actual battery voltage (multiply by divider ratio)
  float batteryVoltage = dividerVoltage * VOLTAGE_DIVIDER_RATIO;
  
  return batteryVoltage;
}

// Calculate battery percentage
int getBatteryPercentage(float voltage) {
  if (voltage >= BATTERY_MAX_VOLTAGE) return 100;
  if (voltage <= BATTERY_MIN_VOLTAGE) return 0;
  
  // Linear interpolation between min and max
  float percentage = ((voltage - BATTERY_MIN_VOLTAGE) / 
                     (BATTERY_MAX_VOLTAGE - BATTERY_MIN_VOLTAGE)) * 100.0;
  
  return constrain((int)percentage, 0, 100);
}

// Get battery icon character based on percentage
String getBatteryIcon(int percentage) {
  if (percentage >= 80) return "====";
  else if (percentage >= 60) return "=== ";
  else if (percentage >= 40) return "==  ";
  else if (percentage >= 20) return "=   ";
  else return "!   "; // Low battery warning
}

/* ---------- Time ---------- */
String isoTimestampUTC() {
  time_t now;
  time(&now);
  struct tm utc;
  gmtime_r(&now, &utc);
  char buf[30];
  strftime(buf, sizeof(buf), "%Y-%m-%dT%H:%M:%SZ", &utc);
  return String(buf);
}

String localTimestamp() {
  struct tm t;
  getLocalTime(&t);
  char buf[30];
  strftime(buf, sizeof(buf), "%Y-%m-%d %H:%M:%S", &t);
  return String(buf);
}

String minuteDocId() {
  struct tm t;
  getLocalTime(&t);
  char buf[20];
  strftime(buf, sizeof(buf), "%Y%m%d_%H%M", &t);
  return String(buf);
}

/* ---------- Run Score Calculation ---------- */

// Convert eCO2 to score (0-100)
float getECO2Score(int eco2) {
  // Lower CO2 is better
  // < 400 ppm = 100, 400-1000 = linear decrease, > 5000 = 0
  if (eco2 < 400) return 100.0;
  if (eco2 > 5000) return 0.0;
  return max(0.0, 100.0 - ((eco2 - 400) / 46.0));
}

// Convert TVOC to score (0-100)
float getTVOCScore(int tvoc) {
  // Lower TVOC is better
  // < 65 ppb = 100, 65-220 = good, 220-660 = moderate, > 2200 = 0
  if (tvoc < 65) return 100.0;
  if (tvoc > 2200) return 0.0;
  return max(0.0, 100.0 - ((tvoc - 65) / 21.35));
}

// Convert Temperature to score (0-100)
float getTempScore(float temp) {
  // Optimal running temp: 10-20°C
  // 10-20°C = 100, decrease outside this range
  if (temp >= 10 && temp <= 20) return 100.0;
  if (temp < 0 || temp > 40) return 0.0;
  
  if (temp < 10) {
    // 0°C = 50, 10°C = 100
    return 50.0 + (temp * 5.0);
  } else {
    // 20°C = 100, 40°C = 0
    return max(0.0, 100.0 - ((temp - 20) * 5.0));
  }
}

// Convert Humidity to score (0-100)
float getHumScore(float hum) {
  // Optimal humidity: 40-60%
  // 40-60% = 100, decrease outside this range
  if (hum >= 40 && hum <= 60) return 100.0;
  if (hum < 10 || hum > 90) return 0.0;
  
  if (hum < 40) {
    // 10% = 0, 40% = 100
    return (hum - 10) * 3.33;
  } else {
    // 60% = 100, 90% = 0
    return max(0.0, 100.0 - ((hum - 60) * 3.33));
  }
}

// Calculate Runner AQI (0-100)
float calculateRunnerAQI(int eco2, int tvoc, float temp, float hum) {
  float eco2_score = getECO2Score(eco2);
  float tvoc_score = getTVOCScore(tvoc);

  // 2. DOMINANT POLLUTANT: Health is dictated strictly by the WORST metric
  float health_aqi = min(eco2_score, tvoc_score);

  float temp_score = getTempScore(temp);
  float hum_score = getHumScore(hum);

  // Comfort is a blend of heat and humidity
  float comfort_score = (temp_score * 0.6) + (hum_score * 0.4); 
  
  // 4. Apply Comfort as a Scaling Penalty
  // Poor comfort degrades a runner's performance even in perfect air,
  // but perfect comfort cannot magically fix toxic air.
  // This multiplier ranges from 0.5 (terrible comfort) to 1.0 (perfect comfort).
  float comfort_multiplier = 0.5 + (comfort_score / 200.0);
  
  float runner_aqi = health_aqi * comfort_multiplier;

  return runner_aqi;
}

// Get status based on Runner AQI
String getStatus(float score) {
  if (score >= 85) return "SAFE";
  else if (score >= 70) return "LOW RISK";
  else if (score >= 50) return "CAUTION";
  else if (score >= 30) return "UNSAFE";
  else return "DANGEROUS";
}

/* ---------- Firebase Auth ---------- */
void getToken() {
  WiFiClientSecure client;
  client.setInsecure();
  HTTPClient http;

  http.begin(client,
    "https://identitytoolkit.googleapis.com/v1/accounts:signUp?key=" API_KEY);
  http.addHeader("Content-Type", "application/json");

  if (http.POST("{}") > 0) {
    StaticJsonDocument<512> doc;
    deserializeJson(doc, http.getString());
    idToken = doc["idToken"].as<String>();
  }
  http.end();
}

/* ---------- Firestore Write ---------- */
void sendToFirestore(
  float t, float h,
  int aqi, int eco2, int tvoc,
  float runner_aqi, float batteryVoltage, int batteryPercent
) {
  WiFiClientSecure client;
  client.setInsecure();
  HTTPClient http;

  String url =
    "https://firestore.googleapis.com/v1/projects/" PROJECT_ID
    "/databases/(default)/documents/sensor_data/esp32_0/readings/"
    + minuteDocId()
    + "?access_token=" + idToken;

  StaticJsonDocument<512> doc;

  doc["fields"]["temperature"]["doubleValue"] = t;
  doc["fields"]["humidity"]["doubleValue"] = h;
  doc["fields"]["aqi"]["integerValue"] = aqi;
  doc["fields"]["eco2"]["integerValue"] = eco2;
  doc["fields"]["tvoc"]["integerValue"] = tvoc;
  doc["fields"]["runner_aqi"]["doubleValue"] = runner_aqi;
  doc["fields"]["battery_voltage"]["doubleValue"] = batteryVoltage;
  doc["fields"]["battery_percent"]["integerValue"] = batteryPercent;
  doc["fields"]["timestamp"]["stringValue"] = isoTimestamp();

  String json;
  serializeJson(doc, json);

  http.begin(client, url);
  http.addHeader("Content-Type", "application/json");
  http.sendRequest("PATCH", json);
  http.end();
}

/* ---------- Draw Battery Icon (top-right) ---------- */
void drawBatteryIcon(int percent) {
  // Battery body: 22x10 px, top-right corner (x=104, y=1)
  const int bx = 104, by = 1, bw = 22, bh = 10;

  // Outer rectangle
  display.drawRect(bx, by, bw, bh, SSD1306_WHITE);

  // Battery tip (nub) on the right side
  display.fillRect(bx + bw, by + 3, 2, 4, SSD1306_WHITE);

  // Fill level (leave 1px padding inside)
  int fillW = map(constrain(percent, 0, 100), 0, 100, 0, bw - 4);
  if (fillW > 0) {
    display.fillRect(bx + 2, by + 2, fillW, bh - 4, SSD1306_WHITE);
  }
}

/* ---------- Display Runner Dashboard ---------- */
void drawRunnerDashboard(float runScore, float temp, float hum, int eco2, int tvoc, 
                        float batteryVoltage, int batteryPercent) {
  display.clearDisplay();

  // ========== TOP RIGHT: Battery icon + percentage ==========
  // Percentage text (right-aligned before icon)
  display.setTextSize(1);
  char batStr[5];
  snprintf(batStr, sizeof(batStr), "%d%%", batteryPercent);
  int textX = 100 - (strlen(batStr) * 6);  // 6px per char at textSize 1
  display.setCursor(textX, 2);
  display.print(batStr);

  // Draw the battery icon
  drawBatteryIcon(batteryPercent);

  // Separator line
  display.drawFastHLine(0, 13, SCREEN_WIDTH, SSD1306_WHITE);
  
  // ========== MAIN SECTION: Run Score ==========
  display.setTextSize(1);
  display.setCursor(2, 16);
  display.print("Run Score");

  // Large score number
  display.setTextSize(3);
  int scoreInt = (int)runScore;
  if (scoreInt < 10) {
    display.setCursor(50, 26);
  } else if (scoreInt < 100) {
    display.setCursor(40, 26);
  } else {
    display.setCursor(30, 26);
  }
  display.print(scoreInt);
    
  // ========== BOTTOM: Status ==========
  display.setTextSize(1);
  display.setCursor(2, 50);
  display.print("Status: ");
  
  String status = getStatus(runScore);
  display.setTextSize(1);
  display.setCursor(50, 50);
  display.print(status);
  
  // Progress bar
  int barWidth = map(runScore, 0, 100, 10, 126);
  display.fillRect(2, 62, barWidth, 2, SSD1306_WHITE);
  
  display.display();
}

/* ---------- Deep Sleep Functions ---------- */

// Print the wakeup reason
void printWakeupReason() {
  esp_sleep_wakeup_cause_t wakeup_reason;
  wakeup_reason = esp_sleep_get_wakeup_cause();

  switch(wakeup_reason) {
    case ESP_SLEEP_WAKEUP_EXT0: 
      Serial.println("Wakeup caused by external signal using RTC_IO (Touch Sensor)");
      break;
    case ESP_SLEEP_WAKEUP_EXT1: 
      Serial.println("Wakeup caused by external signal using RTC_CNTL");
      break;
    case ESP_SLEEP_WAKEUP_TIMER: 
      Serial.println("Wakeup caused by timer");
      break;
    case ESP_SLEEP_WAKEUP_TOUCHPAD: 
      Serial.println("Wakeup caused by touchpad");
      break;
    case ESP_SLEEP_WAKEUP_ULP: 
      Serial.println("Wakeup caused by ULP program");
      break;
    default: 
      Serial.printf("Wakeup was not caused by deep sleep: %d\n", wakeup_reason);
      break;
  }
}

// Enter deep sleep mode
void enterDeepSleep() {
  Serial.println("=============================");
  Serial.println("ENTERING DEEP SLEEP MODE");
  Serial.println("Touch sensor to wake up...");
  Serial.println("=============================");
  
  // Read battery one more time before sleep
  float batteryV = readBatteryVoltage();
  int batteryP = getBatteryPercentage(batteryV);
  
  // Display sleep message
  display.clearDisplay();
  display.setTextSize(1);
  display.setCursor(10, 5);
  display.println("   SLEEP MODE");
  display.println("");
  display.println("  Touch sensor");
  display.println("   to wake up");
  display.println("");
  display.printf("  Boots: %d", bootCount);
  display.println("");
  display.printf("  Batt: %d%% %.2fV", batteryP, batteryV);
  display.display();
  
  delay(2000);  // Show message for 2 seconds
  
  // Turn off display
  display.clearDisplay();
  display.display();
  
  // Configure wake-up source
  // Wake up when GPIO 13 goes HIGH (touch sensor is touched)
  esp_sleep_enable_ext0_wakeup(GPIO_NUM_13, 1);
  
  // Optional: Add timer wakeup as backup (e.g., wake every 10 minutes)
  // esp_sleep_enable_timer_wakeup(10 * 60 * 1000000ULL);  // 10 minutes
  
  Serial.flush();  // Wait for serial to finish
  
  // Enter deep sleep
  esp_deep_sleep_start();
  
  // Code never reaches here - ESP32 resets on wake
}

/* ---------- Touch Sensor Handling ---------- */

// Check if touch sensor is pressed (with debouncing)
bool isTouchPressed() {
  int currentState = digitalRead(TOUCH_PIN);
  unsigned long currentTime = millis();
  
  // Check if state changed and debounce time passed
  if (currentState == HIGH && lastTouchState == LOW) {
    if (currentTime - lastTouchTime > TOUCH_DEBOUNCE) {
      lastTouchTime = currentTime;
      lastTouchState = currentState;
      return true;
    }
  }
  
  lastTouchState = currentState;
  return false;
}

/* ---------- Setup ---------- */
void setup() {
  Serial.begin(115200);
  delay(1000);
  
  // Configure ADC for battery monitoring
  analogReadResolution(12);  // 12-bit resolution (0-4095)
  analogSetAttenuation(ADC_11db);  // Full range: 0-3.3V
  pinMode(BATTERY_PIN, INPUT);
  Serial.println("Battery monitoring configured on GPIO6");
  
  // Increment boot count
  bootCount++;
  
  Serial.println("=================================");
  Serial.println("=== RUNNER AQI SYSTEM (v2.1) ===");
  Serial.println("=== With Battery Monitoring  ===");
  Serial.println("=================================");
  Serial.printf("Boot count: %d\n", bootCount);
  
  // Print wakeup reason
  printWakeupReason();
  
  // Read initial battery level
  float initialBatteryV = readBatteryVoltage();
  int initialBatteryP = getBatteryPercentage(initialBatteryV);
  Serial.printf("Battery: %.2fV (%d%%)\n", initialBatteryV, initialBatteryP);
  
  // Configure touch sensor pin
  pinMode(TOUCH_PIN, INPUT);
  Serial.printf("Touch sensor configured on GPIO %d\n", TOUCH_PIN);
  
  Wire.begin(8, 9); 
  Serial.println("I2C Initialized");

  // Init OLED
  if(!display.begin(SSD1306_SWITCHCAPVCC, SCREEN_ADDRESS)) {
    Serial.println(F("SSD1306 allocation failed"));
    for(;;); 
  }
  Serial.println("OLED Initialized");
  
  display.clearDisplay();
  display.setTextColor(SSD1306_WHITE);

  // Project name - large, centered
  display.setTextSize(2);
  display.setCursor(4, 4);
  display.print("Smart");
  display.setCursor(4, 22);
  display.print("RunSense");

  // Divider
  display.drawFastHLine(0, 43, SCREEN_WIDTH, SSD1306_WHITE);

  // Sub-info row
  display.setTextSize(1);
  display.setCursor(0, 47);
  display.printf("v2.1  Boot#%d", bootCount);
  display.setCursor(0, 57);
  display.printf("Batt: %d%%  %.2fV", initialBatteryP, initialBatteryV);

  display.display();
  Serial.println("OLED Display Updated");

  Serial.print("Connecting to WiFi: ");
  Serial.println(WIFI_SSID);
  
  WiFi.begin(WIFI_SSID, WIFI_PASS);
  int attempts = 0;
  while (WiFi.status() != WL_CONNECTED) {
    delay(500);
    Serial.print(".");
    attempts++;
    
    if(attempts > 40) { // 20 seconds timeout
      Serial.println("\nWiFi connection failed!");
      display.clearDisplay();
      display.setCursor(0, 10);
      display.println("WiFi Failed!");
      display.println("");
      display.println("Touch to retry");
      display.println("");
      display.println("Check:");
      display.println("- SSID/Password");
      display.display();

      // Wait for touch sensor to retry WiFi instead of hard-locking
      Serial.println("Touch sensor to retry WiFi...");
      while (true) {
        if (isTouchPressed()) {
          Serial.println("Touch detected — retrying WiFi...");
          display.clearDisplay();
          display.setCursor(0, 10);
          display.println("Retrying WiFi...");
          display.display();
          WiFi.disconnect(true);
          delay(500);
          WiFi.begin(WIFI_SSID, WIFI_PASS);
          attempts = 0;  // Reset attempt counter to re-enter outer while loop
          break;         // Break inner loop, outer while(WiFi!=connected) resumes
        }
        delay(50); // Small yield to avoid watchdog trigger
      }
    }
  }
  
  Serial.println("\nWiFi Connected!");
  display.clearDisplay();
  display.setCursor(0, 10);
  display.println("WiFi Connected!");
  display.println("");
  display.print("IP: ");
  display.println(WiFi.localIP());
  display.display();

  configTime(5.5 * 3600, 0, "pool.ntp.org");
  
  delay(1000);
  display.clearDisplay();
  display.setCursor(0, 10);
  display.println("Getting Auth Token...");
  display.display();
  
  getToken();

  // Init Sensors
  display.clearDisplay();
  display.setCursor(0, 10);
  display.println("Initializing Sensors...");
  display.display();
  
  if (!aht.begin()) {
    Serial.println("AHT Sensor failed");
    display.clearDisplay();
    display.setCursor(0, 10);
    display.println("ERROR:");
    display.println("AHT Sensor Failed!");
    display.display();
    delay(3000);
  } else {
    Serial.println("AHT Sensor OK");
  }
  
  if (!ens160.begin()) {
    Serial.println("ENS160 Sensor failed");
    display.clearDisplay();
    display.setCursor(0, 10);
    display.println("ERROR:");
    display.println("ENS160 Sensor Failed!");
    display.display();
    delay(3000);
  } else {
    Serial.println("ENS160 Sensor OK");
  }
  
  ens160.setOperatingMode(SFE_ENS160_STANDARD);

  display.clearDisplay();
  display.setCursor(0, 15);
  display.println("   System Ready!");
  display.println("");
  display.println(" Touch to Sleep");
  display.display();
  
  Serial.println("\n>>> Touch sensor to enter deep sleep <<<\n");
  
  delay(2000);
  lastRead = millis() - READ_INTERVAL;
}

/* ---------- Loop ---------- */
void loop() {
  if (idToken == "") return;

  // ========== TOUCH SENSOR CHECK ==========
  // Check for touch to enter deep sleep
  if (isTouchPressed()) {
    Serial.println("\n>>> TOUCH DETECTED - Entering Deep Sleep <<<\n");
    delay(100);  // Small delay for debouncing
    enterDeepSleep();  // Never returns
  }
  
  // ========== SENSOR READING ==========
  if (millis() - lastRead >= READ_INTERVAL) {
    lastRead = millis();

    /* ---- Battery Reading ---- */
    float batteryVoltage = readBatteryVoltage();
    int batteryPercent = getBatteryPercentage(batteryVoltage);

    /* ---- Temp & Hum (AHT) ---- */
    sensors_event_t hum, temp;
    aht.getEvent(&hum, &temp);

    /* ---- ENS160 ---- */
    ens160.setTempCompensation(temp.temperature);
    ens160.setRHCompensation(hum.relative_humidity);

    int aqi  = ens160.getAQI();
    int eco2 = ens160.getECO2();
    int tvoc = ens160.getTVOC();

    /* ---- Calculate Runner AQI ---- */
    float runnerScore = calculateRunnerAQI(eco2, tvoc, temp.temperature, hum.relative_humidity);
    
    /* ---- Display Update ---- */
    drawRunnerDashboard(runnerScore, temp.temperature, hum.relative_humidity, 
                       eco2, tvoc, batteryVoltage, batteryPercent);

    /* ---- Serial Debug ---- */
    Serial.println("=============================");
    Serial.println("RUNNER AQI REPORT");
    Serial.println(isoTimestamp());
    Serial.println("-----------------------------");
    Serial.printf("Battery: %.2fV (%d%%)\n", batteryVoltage, batteryPercent);
    Serial.println("-----------------------------");
    Serial.printf("eCO2: %d ppm (Score: %.1f)\n", eco2, getECO2Score(eco2));
    Serial.printf("TVOC: %d ppb (Score: %.1f)\n", tvoc, getTVOCScore(tvoc));
    Serial.printf("Temp: %.1f C (Score: %.1f)\n", temp.temperature, getTempScore(temp.temperature));
    Serial.printf("Humidity: %.1f %% (Score: %.1f)\n", hum.relative_humidity, getHumScore(hum.relative_humidity));
    Serial.println("-----------------------------");
    Serial.printf("RUNNER SCORE: %.1f\n", runnerScore);
    Serial.printf("STATUS: %s\n", getStatus(runnerScore).c_str());
    Serial.println("=============================\n");

    sendToFirestore(
      temp.temperature,
      hum.relative_humidity,
      aqi,
      eco2,
      tvoc,
      runnerScore,
      batteryVoltage,
      batteryPercent
    );
  }
}

/* ---------- NOTES ON BATTERY VOLTAGE DIVIDER ---------- */
/*
 * Hardware Setup:
 * - Battery (+) ---- 100kΩ ---- GPIO6 (ADC) ---- 100kΩ ---- GND
 * 
 * The voltage divider creates Vout = Vin × (R2 / (R1 + R2))
 * With equal resistors: Vout = Vin × 0.5
 * 
 * Maximum safe ADC input: 3.3V
 * Maximum battery voltage measurable: 3.3V × 2 = 6.6V
 * 
 * Calibration Tips:
 * 1. Measure your actual battery voltage with a multimeter
 * 2. Compare with the voltage reported by the code
 * 3. Adjust VOLTAGE_DIVIDER_RATIO if needed (actual ratio may vary due to resistor tolerance)
 * 4. Adjust BATTERY_MAX_VOLTAGE and BATTERY_MIN_VOLTAGE based on your battery type:
 *    - LiPo: 4.2V (full) to 3.0V (empty)
 *    - Li-ion: 4.2V (full) to 3.0V (empty)
 *    - 3.7V LiPo: Use values above
 * 
 * To calibrate the voltage divider ratio:
 * 1. Measure real battery voltage with multimeter: e.g., 4.05V
 * 2. Note the voltage displayed by the code (before calibration): e.g., 1.22V
 * 3. Calculate correction: VOLTAGE_DIVIDER_RATIO = (4.05 / 1.22) × 2.0 = 6.639
 *    (multiply by old ratio of 2.0 since the base divider uses equal resistors)
 * 4. Update the #define VOLTAGE_DIVIDER_RATIO value
 * 
 * *** CALIBRATED VALUES (your hardware) ***
 * Multimeter reading : 4.05V
 * Code displayed     : 1.22V  (with old ratio = 2.0)
 * Calibrated ratio   : 6.639  ✓ (currently applied)
 */

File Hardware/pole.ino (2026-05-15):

#include <WiFi.h>
#include <HTTPClient.h>
#include <ArduinoJson.h>
#include <WiFiClientSecure.h>
#include <time.h>
#include <Wire.h>
#include <SparkFun_ENS160.h>
#include <Adafruit_AHTX0.h>
#include <LiquidCrystal_I2C.h>

/* ---------- LCD ---------- */
LiquidCrystal_I2C lcd(0x27, 16, 4);

/* ---------- SECRETS (DO NOT COMMIT REAL VALUES TO GITHUB) ---------- */
#define WIFI_SSID "YOUR_WIFI_NAME"
#define WIFI_PASS "YOUR_WIFI_PASSWORD"
#define API_KEY    "YOUR_API_KEY"
#define PROJECT_ID "YOUR_PROJECT_ID"

/* ---------- Sensors ---------- */
SparkFun_ENS160 ens160;
Adafruit_AHTX0 aht;

/* ---------- MQ135 SETTINGS ---------- */
#define MQ135_PIN 4
// Hardware & Calibration Parameters
const float R_load = 10.0;       // Physical 10kΩ resistor on the module
const float R0 = 33.0;           // Your calibrated baseline resistance in clean air
// MQ135 Datasheet Curve Parameters for General Gas / Smoke / Ammonia
const float a = 102.2;           // Scaling number from the datasheet curve
const float b = 2.473;           // Slope number from the datasheet curve

/* ---------- OPTICAL DUST SENSOR SETTINGS (GP2Y1010AU0F) ---------- */
// You may need to change these pins depending on your ESP32 wiring
#define DUST_LED_PIN 32  
#define DUST_OUT_PIN 33  

/* ---------- RESET BUTTON SETTINGS ---------- */
#define RESET_BTN_PIN 14  // Connect Button between GPIO 14 and GND

/* ---------- Timing ---------- */
unsigned long lastRead = 0;
const unsigned long READ_INTERVAL = 60000; // 1 minute
String idToken = "";

/* ---------- MQ135: General Pollution % ---------- */
int readGasPollutionPercentage() {
  int rawValue = analogRead(MQ135_PIN);
  float V_pin = rawValue * (3.3 / 4095.0);
  float V_true = V_pin * 2.0;

  if (V_true >= 5.0 || V_true <= 0) {
    return 0; 
  }

  float Rs = R_load * ((5.0 - V_true) / V_true);
  float ratio = Rs / R0;
  float ppm = a * pow(ratio, -b);
  float percentage = (ppm / 10.0) * 100.0;

  if (percentage < 0) percentage = 0;
  if (percentage > 100) percentage = 100;

  return (int)percentage; 
}

/* ---------- Real Dust Density (GP2Y1010AU0F) ---------- */
float readDustDensity() {
  // The sensor requires a specific pulsing of its internal LED to read the dust particles
  digitalWrite(DUST_LED_PIN, LOW); // Power on the LED
  delayMicroseconds(280);
  
  int voMeasured = analogRead(DUST_OUT_PIN); // Read the dust value
  
  delayMicroseconds(40);
  digitalWrite(DUST_LED_PIN, HIGH); // Turn the LED off
  delayMicroseconds(9680);

  // Convert analog reading to voltage (ESP32 is 12-bit ADC, 3.3V logic)
  float calcVoltage = voMeasured * (3.3 / 4095.0);
  
  // Linear equation from GP2Y1010AU0F datasheet to calculate mg/m3
  float dustDensity = 0.17 * calcVoltage - 0.1;

  if (dustDensity < 0) {
    dustDensity = 0.00; // Prevent negative readings in very clean air
  }
  
  return dustDensity; 
}

/* ---------- Time Utilities ---------- */
String isoTimestampUTC() {
  time_t now;
  time(&now);
  struct tm utc;
  gmtime_r(&now, &utc);
  char buf[30];
  strftime(buf, sizeof(buf), "%Y-%m-%dT%H:%M:%SZ", &utc);
  return String(buf);
}

String localTimestamp() {
  struct tm t;
  getLocalTime(&t);
  char buf[30];
  strftime(buf, sizeof(buf), "%Y-%m-%d %H:%M:%S", &t);
  return String(buf);
}

String minuteDocId() {
  struct tm t;
  getLocalTime(&t);
  char buf[20];
  strftime(buf, sizeof(buf), "%Y%m%d_%H%M", &t);
  return String(buf);
}

/* ---------- Firebase Auth ---------- */
void getToken() {
  WiFiClientSecure client;
  client.setInsecure();
  HTTPClient http;

  http.begin(client,
    "https://identitytoolkit.googleapis.com/v1/accounts:signUp?key=" API_KEY);
  http.addHeader("Content-Type", "application/json");

  if (http.POST("{}") > 0) {
    StaticJsonDocument<512> doc;
    deserializeJson(doc, http.getString());
    idToken = doc["idToken"].as<String>();
  }
  http.end();
}

/* ---------- Firestore Write ---------- */
void sendToFirestore(
  float t, float h,
  int aqi, int eco2, int tvoc,
  float dust, int gasPercent
) {
  WiFiClientSecure client;
  client.setInsecure();
  HTTPClient http;

  String url =
    "https://firestore.googleapis.com/v1/projects/" PROJECT_ID
    "/databases/(default)/documents/sensor_data/esp32/readings/"
    + minuteDocId()
    + "?access_token=" + idToken;

  StaticJsonDocument<768> doc;

  doc["fields"]["temperature"]["doubleValue"] = t;
  doc["fields"]["humidity"]["doubleValue"] = h;
  doc["fields"]["aqi"]["integerValue"] = aqi;
  doc["fields"]["eco2"]["integerValue"] = eco2;
  doc["fields"]["tvoc"]["integerValue"] = tvoc;
  doc["fields"]["dust"]["doubleValue"] = dust;
  doc["fields"]["gas_pollution_percent"]["integerValue"] = gasPercent;
  doc["fields"]["timestamp"]["timestampValue"] = isoTimestampUTC();

  String json;
  serializeJson(doc, json);

  http.begin(client, url);
  http.addHeader("Content-Type", "application/json");
  int code = http.sendRequest("PATCH", json);
  Serial.print("Firestore HTTP: ");
  Serial.println(code);
  http.end();
}

/* ---------- Setup ---------- */
void setup() {
  Serial.begin(115200);

  // Setup Reset Button Pin
  pinMode(RESET_BTN_PIN, INPUT_PULLUP);
  
  // Setup Dust Sensor Pins
  pinMode(DUST_LED_PIN, OUTPUT);
  pinMode(DUST_OUT_PIN, INPUT);
  digitalWrite(DUST_LED_PIN, HIGH); // Sensor LED defaults to OFF

  Wire.begin(21, 20);

  /* ---- LCD ---- */
  lcd.init();
  lcd.backlight();
  lcd.setCursor(0, 0);
  lcd.print("System Init...");
  lcd.setCursor(0, 1);
  lcd.print("WiFi Connecting");

  WiFi.begin(WIFI_SSID, WIFI_PASS);
  while (WiFi.status() != WL_CONNECTED) delay(500);

  lcd.command(0x90);
  lcd.print("WiFi Connected");

  configTime(19800, 0, "pool.ntp.org");
  getToken();

  aht.begin();
  ens160.begin();
  ens160.setOperatingMode(SFE_ENS160_STANDARD);

  delay(2000);
  lcd.clear();

  lastRead = millis() - READ_INTERVAL;
}
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
